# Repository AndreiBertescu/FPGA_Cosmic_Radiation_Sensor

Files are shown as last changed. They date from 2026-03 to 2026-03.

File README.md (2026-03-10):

# FPGA Cosmic Radiation Sensor (AICoRS)

This repository contains all materials related to the development of a cosmic radiation sensor board based on a Field-Programmable Gate Array (FPGA), as part of the project:

**"Artificial Intelligence-enabled Hardware Cosmic Radiation Sensor for Space Applications (AICoRS)"**  
PN-IV-P8-8.3-ROMD-2023-0068, in partnership between Transilvania University of Brașov and the Technical University of Moldova.

---

## Abstract

In the terrestrial space environment, radiation from Galactic Cosmic Rays (GCR), solar events, and trapped particles in the Earth's magnetosphere can interact with electronic circuits and cause **Single Event Effects (SEE)**, such as **Single Event Upsets (SEU)** and **Single Event Transients (SET)**. These effects pose significant challenges for high-performance and critical space systems, requiring dedicated detection methods and mitigation strategies.

This project presents the **design, implementation, and validation** of an FPGA-based cosmic radiation sensor board. The work includes:  

- FPGA device selection optimized for space applications  
- Hardware Description Language (HDL) development for SEU detection and communication  
- Printed Circuit Board (PCB) design for nanosatellite integration  
- Testing and validation of all components  
- Theoretical analysis of the space radiation environment and conversion of physical radiation parameters to memory bit change rates  

The developed sensor board has successfully passed validation and will be integrated with two other radiation detectors and a local On-Board Computer (OBC) as a Moldovan payload in the 3U **BIRDS-RPM** nanosatellite, scheduled for launch into **Low Earth Orbit (LEO)** via a resupply mission to the **International Space Station (ISS)** by **JAXA**.

---

## Repository Structure
FPGA_Cosmic_Radiation_Sensor<br>
├─ Arduino Test projects       --- Arduino experiments and test code <br>
├─ Kicad PCB projects          --- PCB designs for sensor board <br>
├─ Thesis latex project        --- Full thesis LaTeX source <br>
├─ Thesis latex template       --- Custom LaTeX template for IESC faculty <br>
├─ Verilog parts test projects --- Test benches and simulation projects for various subsystems <br>
├─ Verilog source code - V7.10 --- Full latest FPGA HDL source code for SEU detection <br>
├─ .gitignore                  --- Git ignore for Vivado, KiCdas, Latex and generated files <br>
├─ LICENSE                     --- CC BY-NC 4.0 license <br>
├─ LICENTA_Final.pdf           --- Final compiled thesis PDF <br>
├─ README.md                   --- This file <br>

---

## License

This work is licensed under a **[Creative Commons Attribution-NonCommercial 4.0 International License (CC BY-NC 4.0)](https://creativecommons.org/licenses/by-nc/4.0/)**.  

You are free to **share** and **adapt** the content for **non-commercial purposes**, with proper attribution to the author.

---

## Publications

The work conducted in this project has led to several scientific publications covering different stages, results, and aspects of the system development:

1. **Preliminary SEU Detection Algorithm**  
S. Popa, A. Kazak, A. Dinu et al., *“Architecture and Design Choices for an AI-enabled FPGA-based Cosmic Radiation Sensor,”* in 2024 International Symposium on Electronics and Telecommunications (ISETC), 2024, pp. 1–4.  
DOI: [10.1109/ISETC63109.2024.10797366](https://doi.org/10.1109/ISETC63109.2024.10797366)

2. **BIRDS Project Architecture & FPGA Sensor Comparison**  
N. Secrieru, V. Carbune, T. Zadorojneac et al., *“ARCHITECTURE OF THE SPACE RADIATION SENSOR SATELLITE MODULE BASED ON ARTIFICIAL INTELLIGENCE,”* JOURNAL OF ENGINEERING SCIENCE, vol. 31, nr. 4, pp. 73–83, Jan. 2025.  
DOI: [10.52326/jes.utm.2024.31(4).05](https://press.utm.md/index.php/jes/article/view/2024-31-4-05)

3. **FPGA-Based Radiation Sensor PCB Design**  
A. Bertescu and S. Popa, *“The Design and Implementation of an FPGA-Based Cosmic Radiation Sensor PCB,”* in 2025 18th International Conference on Engineering of Modern Electric Systems (EMES), 2025, pp. 1–4.  
DOI: [10.1109/EMES65692.2025.11045622](https://doi.org/10.1109/EMES65692.2025.11045622)

4. **Power and Cross-Section Optimization for FPGA Sensor**  
S. Popa, A. Bertescu, C. Furtună et al., *“Power and Cross-Section Optimization for an FPGA-Based Cosmic Radiation Sensor,”* in 2025 32nd IEEE International Conference on Electronics, Circuits and Systems (ICECS), 2025, pp. 1–4.

---

## Photos
### <br>Final AICoRS board
Photo no longer available

### <br>3D render of the AICoRS board
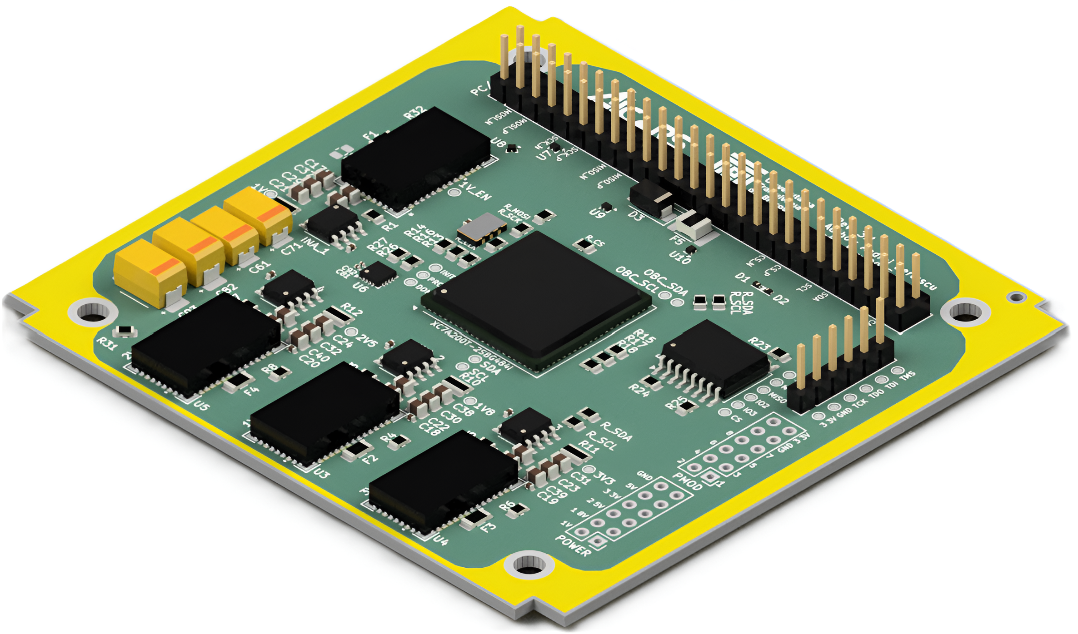
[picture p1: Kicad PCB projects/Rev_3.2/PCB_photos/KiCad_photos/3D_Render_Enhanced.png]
Photo no longer available


### <br>First version vs final version of the PCBs
Photo no longer available

### <br>BIRDS nanosatellite diagram 
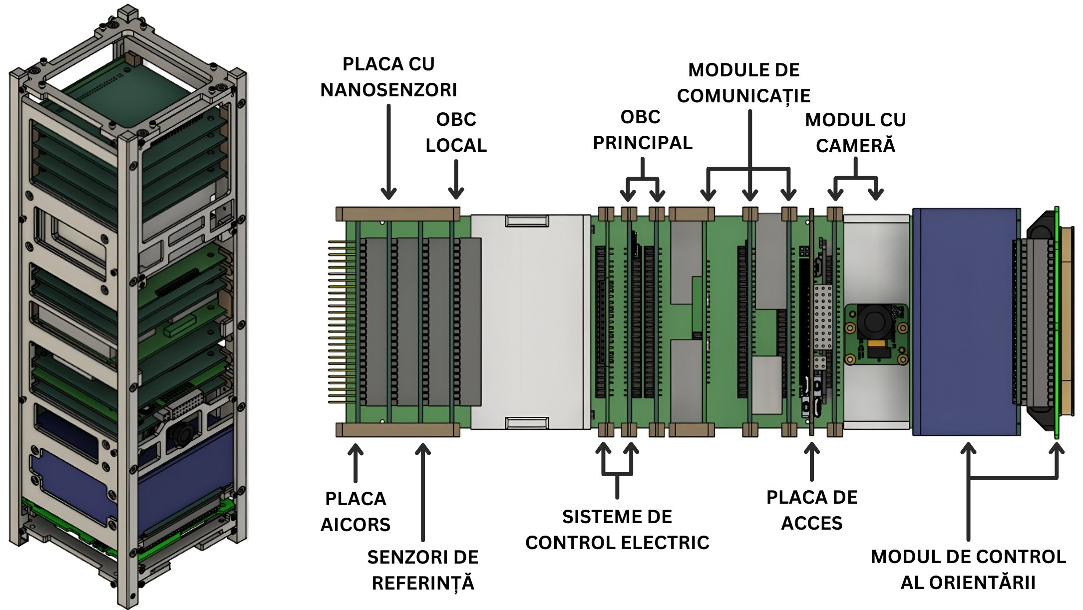
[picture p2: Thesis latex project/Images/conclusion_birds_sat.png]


### <br>Verilog program diagram
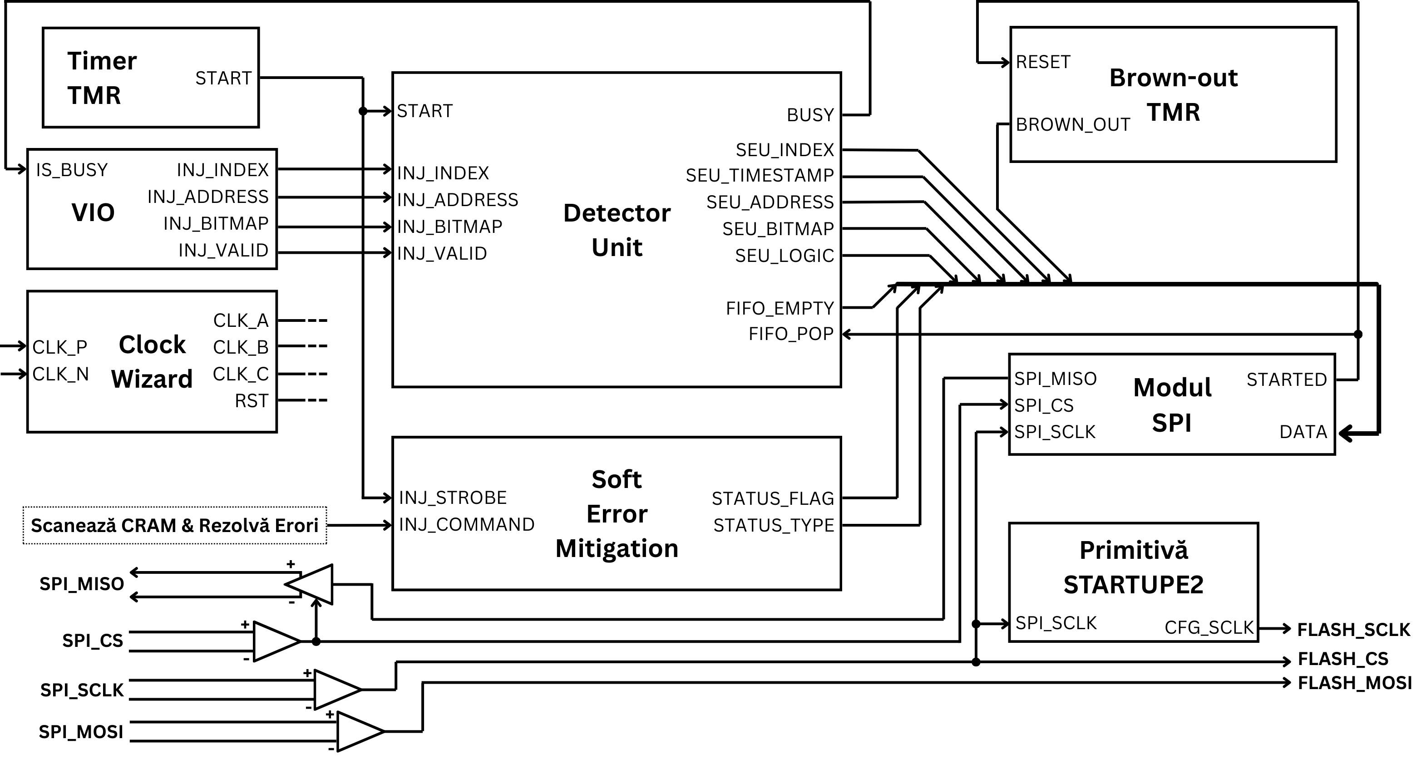
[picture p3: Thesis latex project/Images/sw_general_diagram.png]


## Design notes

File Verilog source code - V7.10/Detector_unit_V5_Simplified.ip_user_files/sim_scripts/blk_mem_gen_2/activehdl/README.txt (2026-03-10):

################################################################################
# Vivado (TM) v2024.1 (64-bit)
#
# README.txt: Please read the sections below to understand the steps required to
#             run the exported script and how to fetch design source file details
#             from the file_info.txt file.
#
# Generated by export_simulation on Mon Feb 03 11:43:21 +0200 2025
#
################################################################################

1. Steps to run the generated simulation script

From the shell prompt in the current directory, issue the following command:-

./blk_mem_gen_2.sh

This command will launch the 'compile', 'elaborate' and 'simulate' functions
implemented in the script file for the 3-step flow. These functions are called
from the main 'run' function in the script file.

The 'run' function first calls the 'check_args' function, the purpose of which
is to verify the generated script arguments and print error if incorrect switch
is specified. The 'run' function then calls the 'setup' function, the purpose of
which is to specify custom or initialization commands. The function also executes
following sub-functions:-
'reset_run' if -reset_run switch is specified.
'reset_log' if -reset_log switch is specified.

The purpose of 'reset_run' function' is to delete the simulator generated design
data from the previous run and the purpose of 'reset_log' function' is to delete
the simulator generated log files.

The 'run' function then calls the 'init_lib' function, the purpose of which is to
create design library mappings and directories. This function is called before the
'compile' step. By default, if '-step' switch is specified with the script then the
script will execute that specfic step, else it will execute all steps applicable
for the target simulator.

For more information on the script, please type './blk_mem_gen_2.sh -help'

2. Design source file information

export_simulation generates a 'file_info.txt' file that contains design file information
based on the compile order when export_simulation was executed from Vivado. The file
contains information about the file name, type, library it is compiled into, whether
it is part of the IP, associated library, file path information in a comma separated
format. This file can be parsed to extract the required information for generating a
custom script or can be read from verification test infra.

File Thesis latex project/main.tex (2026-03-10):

\documentclass[12pt,a4paper]{report}

% --------------------- PACKAGES ---------------------
\usepackage{fontspec}             % Custom font
\usepackage{pdfpages}             % Atach PDFs
\usepackage{graphicx}             % Images
\usepackage{amsmath,amssymb}      % Math
\usepackage{caption}              % Figure/table captions
\usepackage{booktabs}
\usepackage{colortbl}
\usepackage{subcaption}           % Subfigures
\usepackage{geometry}             % Margins
\usepackage{fancyhdr}             % Headers/footers
\usepackage{tocloft}              % ToC/List formatting
\usepackage[acronym,nonumberlist]{glossaries} % Acronyms
\usepackage[hidelinks]{hyperref}  % Hyperlinks
\usepackage{titlesec}             % Section title styling
\usepackage{listings}             % Source code
\usepackage{chngcntr}             % Counter tweaks
\usepackage{tabularx}             % Tables
\usepackage{tikz}                 % Graphs
\usepackage{pgfplots}             % Plots
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
  numberstyle=\scriptsize,
  breaklines=true,
  captionpos=b,
  frame=none,
  showstringspaces=false,
  xleftmargin=0.6cm,
}

% --------------------- ACRONYMS ---------------------
% ------- ADD ALL ACRONYMS HERE - REFERENCE THEM IN TEXT WITH \gls{name}
\newacronym{aicors}{AICoRS}{Artificial Intelligence-enabled Hardware Cosmic Radiation Sensor for Space Applications}
\newacronym{bga}{BGA}{Ball Grid Array}
\newacronym{bram}{BRAM}{Block Random-Access Memory}
\newacronym{can}{CAN}{Controller Area Network}
\newacronym{cmos}{CMOS}{Complementary Metal–Oxide–Semiconductor}
\newacronym{cram}{CRAM}{Configuration Random-Access Memory}
\newacronym{crc}{CRC}{Cyclic Redundancy Check}
\newacronym{cs}{CS}{Chip Select}
\newacronym{de}{DE}{Detector Element}
\newacronym{du}{DU}{Detector Unit}
\newacronym{ecc}{ECC}{Error Correction Code}
\newacronym{eeprom}{EEPROM}{Electrically Erasable Programmable Read-Only Memory}
\newacronym{enig}{ENIG}{Electroless Nickel Immersion Gold}
\newacronym{esa}{ESA}{Agenția Spațială Europeană}
\newacronym{ff}{FF}{Flip-Flop}
\newacronym{fifo}{FIFO}{First In, First Out}
\newacronym{fpga}{FPGA}{Field-Programmable Gate Array}
\newacronym{gcr}{GCR}{Galactic Cosmic Rays}
\newacronym{gpio}{GPIO}{General-Purpose Input/Output}
\newacronym{hdl}{HDL}{Hardware Description Language}
\newacronym{i2c}{I\textsuperscript{2}C}{Inter-Integrated Circuit}
\newacronym{ic}{IC}{Circuit Integrat}
\newacronym{io}{I/O}{Input/Output}
\newacronym{ip}{IP}{Intellectual Property}
\newacronym{iss}{ISS}{Stația spațială internațională}
\newacronym{jaxa}{JAXA}{Agenția Spațială Japoneză}
\newacronym{jtag}{JTAG}{Joint Test Action Group}
\newacronym{lansce}{LANSCE}{Los Alamos Neutron Science Center}
\newacronym{leo}{LEO}{Low Earth Orbit}
\newacronym{let}{LET}{Linear Energy Transfer}
\newacronym{lfsr}{LFSR}{Linear Feedback Shift Register}
\newacronym{lut}{LUT}{Look-Up Table}
\newacronym{lutram}{LUTRAM}{Look-Up Table Random Access Memory}
\newacronym{lvcmos33}{LVCMOS33}{Low-Voltage CMOS 3.3\,V}
\newacronym{lvds}{LVDS}{Low-Voltage Differential Signaling}
\newacronym{miso}{MISO}{Master In Slave Out}
\newacronym{mosfet}{MOSFET}{Metal-Oxide-Semiconductor Field-Effect Transistor}
\newacronym{mosi}{MOSI}{Master Out Slave In}
\newacronym{nasa}{NASA}{Administrația Națională pentru Aeronautică și Spațiu}
\newacronym{npth}{NPTH}{Non-Plated Through Hole}
\newacronym{obc}{OBC}{On-Board Computer}
\newacronym{pcb}{PCB}{Printed Circuit Board}
\newacronym{pmod}{Pmod}{Peripheral Module Interface}
\newacronym{pth}{PTH}{Plated Through Hole}
\newacronym{ram}{RAM}{Random-Access Memory}
\newacronym{rms}{RMS}{Root Mean Square}
\newacronym{sck}{SCK}{Serial Clock}
\newacronym{secded}{SECDED}{Single Error Correction, Double Error Detection}
\newacronym{see}{SEE}{Single Event Effect}
\newacronym{sel}{SEL}{Single Event Latch-up}
\newacronym{sem}{SEM}{Soft Error Mitigation}
\newacronym{set}{SET}{Single Event Transient}
\newacronym{seu}{SEU}{Single Event Upset}
\newacronym{smd}{SMD}{Surface-Mount Device}
\newacronym{spenvis}{SPENVIS}{Space Environment Information System}
\newacronym{spi}{SPI}{Serial Peripheral Interface}
\newacronym{sram}{SRAM}{Static Random-Access Memory}
\newacronym{tb}{TB}{Testbench}
\newacronym{tcl}{TCL}{Tool Command Language}
\newacronym{tht}{THT}{Through-Hole Technology}
\newacronym{tid}{TID}{Total Ionizing Dose}
\newacronym{tmr}{TMR}{Triple Modular Redundancy}
\newacronym{tvs}{TVS}{Transient Voltage Suppression}
\newacronym{uart}{UART}{Universal Asynchronous Receiver-Transmitter}
\newacronym{uram}{URAM}{Ultra Random-Access Memory}
\newacronym{usb}{USB}{Universal Serial Bus}
\newacronym{vio}{VIO}{Virtual Input/Output}
\newacronym{vlsi}{VLSI}{Very Large Scale Integration}

% --------------------- DOCUMENT ---------------------
% ------- UPDATE HERE WITH CORRESPONDING VALUES - NAME & TITLE
\newcommand{\studentname}{Bertescu Andrei}
\newcommand{\projecttitle}{Senzor inteligent de detecție a radiației cosmice, bazat pe FPGA, destinat nanosateliților}

\begin{document}

% ------- THIS DOCUMENT IS MADE SEPARATELY AND ADDED HERE
% ------- NO NEED TO MODIFY HERE
\includepdf[pages=-, pagecommand={\thispagestyle{plainfooter}}]
{Anexe/Prima pagina.pdf}

% ------- THE FOLLOWING PAGES ARE AUTOMATED - NO NEED TO MODIFY
\chapter*{Cuprins}
\vspace{-8em}
\tableofcontents
\newpage

\chapter*{Lista figurilor și tabelelor}
\addcontentsline{toc}{chapter}{Lista figurilor și tabelelor}

\section*{Figuri}
\vspace{-6em}
\listoffigures
\newpage

\section*{Tabele}
\vspace{-6em}
\listoftables
\newpage

\begingroup
\small
\setstretch{0.8}
\printglossary[type=acronym, style=list, nonumberlist, nogroupskip,title=Listă de acronime]
\endgroup
\addcontentsline{toc}{chapter}{Listă de acronime}
\newpage

% ------- THIS IS WHERE THE MAIN CONTENT GOES - EDIT HERE
\chapter{Introducere}
\section{Context și motivație}
Odată cu avansul tehnologic accelerat al umanității și evoluția domeniilor precum electronica, fizica și știința materialelor, aplicațiile aeronautice și spațiale capătă o importanță din ce în ce mai mare. Explorarea acestor medii extreme crește substanțial riscurile cauzate de radiația cosmică intensă prezentă în afara atmosferei. Din acest motiv, există un interes crescut în reducerea acestor pericole, prin studierea efectelor radiației ionizante, îmbunătățirea tehnologiilor de fabricare și protejare a componentelor, precum și detectarea și măsurarea nivelului de radiație. 

Tehnologiile actuale, însă, sunt adesea foarte specializate, folosesc materiale greu accesibile și sunt extrem de costisitoare. Lucrarea de față propune o alternativă mai accesibilă, bazată pe folosirea unui dispozitiv \gls{fpga} relativ ieftin, mai precis un Artix-7 de la Xilinx, pentru implementarea unui senzor inteligent de radiație cosmică. Dispozitivul \gls{fpga} va fi montat pe un \gls{pcb} proiectat să funcționeze la bordul unui nanosatelit de tip CubeSat.
% Acest senzor va integra un model de \gls{ai} pentru clasificarea și gruparea datelor colectate.

\section{Stadiul tehnologiei actuale}
\subsection{Senzori de radiație}
La momentul actual, există o multitudine de detectoare pentru radiație folosiți în acceleratoarele de particule, precum și în aplicații și experimente aerospațiale. Cele mai importante tipuri de senzori pentru detecția radiației cosmice sunt prezentate în~\cite{radiation_sensor_types}. În continuare, vor fi explicate modul de funcționare al fiecăruia și vor fi evidențiate avantajele și dezavantajele în contextul implementării pe un \gls{fpga}.
\begin{itemize}
    \item Detectorul cu ionizare în gaz: este alcătuit dintr-un tub metalic, umplut cu gaz, și un anod central, care măsoară impulsurile de curent cauzate de ionizarea gazului~\cite{gaseours_detectors}. Aceste tipuri de detectoare, precum tubul Geiger–Müller, camera de ionizare sau contorul proporțional, se află printre primele metode de a măsura nivelul de radiație și, deși sunt relativ simple și ușor de implementat în laborator, dimensiunile lor voluminoase le fac neadecvate pentru implementarea într-un nanosatelit.
    \item Detectoare cu scintilație: se folosesc de mai multe tipuri de materiale organice sau anorganice, care au proprietatea de a emite un puls de lumină când sunt traversate de particule ionizante. Lumina creată este amplificată de un tub fotomultiplicator și apoi măsurată. Aceste detectoare oferă un timp de răspuns foarte rapid și pot detecta o gamă largă de particule, însă tubul fotomultiplicator este voluminos, iar consumul de energie este ridicat (tensiuni de ordinul kilovolților pentru funcționare), ceea ce limitează utilizarea lor în aplicații compacte.
    \item Detectoare semiconductoare: funcționează pe baza proprietăților materialelor semiconductoare (siliciu sau germaniu) de a genera semnale electrice în urma ionizării de către o particulă suficient de energetică~\cite{silicon_detectors}. În comparație cu restul tipurilor de detectoare, aceștia par opțiunea ideală pentru aplicații compacte și foarte eficiente energetic. Energia necesară pentru a crea o pereche electron-gol este mult mai mică (3.6 eV) comparativ cu detectoarele pe bază de gaz sau scintilatoare (30 eV, respectiv 300 eV). Cu toate acestea, costurile ridicate de fabricație, necesitatea ecranării și a circuitelor de protecție împotriva zgomotului, precum și sensibilitatea la temperatură și la degradare în timp cauzată de radiație, pot reprezenta dezavantaje în contextul unor misiuni cu resurse limitate.
    \item Detectoare avansate sau dedicate, precum Radiation Assessment Detector (RAD) prezent pe \gls{iss} sau circuitele integrate Medipix~\cite{medipix} sau Radiation-sensing Field-Effect Transistor (RadFET)~\cite{radfet}, oferă performanțe excelente în detectarea radiației cosmice. Totuși, datorită complexității ridicate și costurilor mari, acestea sunt mai puțin potrivite pentru misiuni educaționale sau cu buget limitat.
\end{itemize}

\subsection{Tehnologii de protecție a cablajelor imprimate}
Cablajele imprimate destinate funcționării în mediul extrem al spațiului sunt nevoite să reziste vibrațiilor intense generate în timpul decolării, variațiilor termice extreme și radiației cosmice. Aceste \gls{pcb}-uri trebuie să adere standardelor stricte impuse de \gls{nasa} sau \gls{esa}~\cite{esa_pcb_standards} și trebuie să fie supuse unor teste extinse și costisitoare, fapt nepracticabil pentru proiecte relativ mici, provenite din mediile universitare sau de cercetare. Materialele utilizate în fabricarea \gls{pcb}-urilor aerospațiale sunt, de asemenea, costisitoare și greu accesibile, necesitând adesea colaborarea cu servicii de producție specializate. Se preferă materiale cu proprietăți termice superioare și performanță mai bună în vid, cum ar fi poliamidă sau variante modificate de FR-4. De multe ori, pentru protecția împotriva oxidării și pentru a întări rezistența structurală, marginile plăcii și zonele cu metal expus sunt acoperite cu un strat de tip \gls{enig}.

Componentele montate pe aceste \gls{pcb}-uri sunt la rândul lor selectate cu mare atenție, favorizându-se cele ce au mai fost utilizate în cadrul altor misiuni spațiale. Aceste componente trebuie să respecte toleranțe stricte și să reziste la temperaturi extreme, între -55 $^{\circ}$ C și +125 $^{\circ}$ C, depășind cerințele aplicațiilor comerciale. Totodată, toate elementele trebuie să fie întărite împotriva radiației (radiation hardened) sau să fie testate și recomandate de către agențiile spațiale~\cite{nasa_recomended_parts}. Se preferă pachetele ceramice sau metalice, în locul învelișurilor plastice. Pentru a îmbunătăți și mai mult rezistența la radiație și la zgomotul electromagnetic, componentele sensibile pot fi încapsulate într-o carcasă metalică, iar întregul \gls{pcb} poate fi acoperit cu un strat protector conform, care asigură protecție împotriva coroziunii, umidității și prafului.

\section{Obiective și constrângeri}
Pentru ca această placă să funcționeze fiabil în mediul spațial și să poată fi integrată într-un nanosatelit, trebuie să depășească mai multe provocări generate de condițiile extreme și spațiul redus. În primul rând, \gls{pcb}-ul trebuie să fie compact, având dimensiunile fixe de 86 $\times$ 90 $\times$ 11 mm, cu un spațiu și mai mic pentru plasarea componentelor. Consumul de energie nu trebuie să depășească 2 W, iar sistemul trebuie să reziste la pierderi bruște de alimentare și la vârfuri de tensiune. Toată placa interfațează cu restul satelitului printr-un singur conector cu 52 de pini, ceea ce înseamnă că toate interfețele de comunicare și liniile de alimentare pornesc din aceeași zonă a plăcii. Pentru alimentarea \gls{fpga}-ului sunt necesare patru tensiuni diferite: 3.3 V, 2.5 V, 1.8 V și 1 V, tensiuni care trebuie generate local, satelitul furnizând doar 5 V. Comunicarea \gls{fpga}-ului cu \gls{obc}-ul satelitului se realizează printr-o singură interfață \gls{lvds} \gls{spi}, alte interfețe fiind disponibile, dar considerate neprioritare. În plus, dispozitivul trebuie să fie autonom față de restul satelitului și să nu necesite configurare externă \gls{pcb}-ului. Din acest motiv, fișierele de configurare sunt stocate pe un cip de memorie non-volatilă amplasat lângă \gls{fpga}.

În calitate de componentă activă a plăcii, \gls{fpga}-ul trebuie să detecteze radiația cosmică (în special \gls{seu}, detaliați în Capitolul~\ref{cosmic_radiation_theory}), să înregistreze aceste evenimente și, la un interval precizat, să le transmită \gls{obc}-ului prin interfața \gls{lvds} \gls{spi}. Totodată, \gls{fpga}-ul monitorizează consumul de curent și nivelele de tensiune atât ale cipului, cât și ale celor patru șine de alimentare, comunicând prin interfața \gls{i2c} cu patru senzori de curent integrați pe \gls{pcb}. Fiind susceptibil radiației cosmice, acesta trebuie să utilizeze metode de protecție, precum \gls{tmr}, pentru prevenirea erorilor, să monitorizeze integritatea memoriei sale de configurare, iar în cazul apariției unor erori, să repare partea afectată sau să se reprogrameze folosind configurări stocate pe cipul de memorie non-volatilă.

Obiectivul principal al acestei lucrări este documentarea procesului de proiectare, implementare și testare a unui senzor de radiație cosmică bazat pe un \gls{fpga}, precum și a unui \gls{pcb} capabil să susțină funcționarea acestui detector. Dispozitivul realizat trebuie să depășească provocările tehnice menționate, atât la nivel software, cât și hardware, și să fie pregătit pentru integrare într-un nanosatelit. Pe partea software, va fi detaliat procesul de proiectare, simulare și testare a programului Verilog menit să detecteze radiația cosmică, să comunice cu \gls{obc}-ul și cu alte dispozitive de pe \gls{pcb}, și să mențină integritatea acestuia. Partea hardware va documenta alegerea \gls{fpga}-ului ideal, proiectarea \gls{pcb}-ului suport, testarea ansamblului și rezolvarea problemelor găsite. De asemenea, lucrarea va include o analiză a costurilor și a consumului de energie, precum și o evaluare a fezabilității implementării în mediul spațial real. În final, lucrarea urmărește să demonstreze că soluțiile propuse pot prezenta o alternativă fiabilă și eficientă la sistemele tradiționale de detecție a radiației, în special pentru misiuni științifice cu buget redus sau proiecte academice dedicate explorării spațiului.

\section{Structura lucrării}
Lucrarea este structurată în trei părți principale, organizate cronologic în funcție de desfășurarea proiectului. În completarea acestor capitole principale, lucrarea va conține și o parte teoretică introductivă, menită să ofere cititorului un context adecvat, precum și o secțiune finală de concluzii și sugestii pentru îmbunătățiri viitoare, în care sunt prezentate rezultatele obținute, direcții de dezvoltare și pașii următori. 

Prima parte va detalia toate aspectele legate de \gls{fpga}: de la alegerea dispozitivului potrivit,  până la proiectarea structurii de detecție a radiației, dezvoltarea modulelor de comunicație, precum și testarea și simularea acestora. A doua parte documentează procesul de proiectare a \gls{pcb}-ului și procesul de rezolvare a constrângerilor impuse de montarea într-un satelit. Este descrisă proiectarea primei versiuni a plăcii prototip, identificarea erorilor și îmbunătățirea acesteia, finalizată prin realizarea unei a doua versiuni, care are rolul de variantă finală, pregătită pentru lansare. Ultima parte tratează metodologia de testare a întregului ansamblu, precum și a componentelor individuale, din punct de vedere electric și funcțional. Sunt incluse teste termale, măsurători de consum și de integritate a semnalului, dar și verificări ale funcționării corecte a \gls{fpga}-ului și ale comunicației acestuia cu \gls{obc}-ul și alți senzori conectați.

\section{Mențiuni și contextul proiectului AICoRS}
Această lucrare se bazează pe activitatea desfășurată în cadrul proiectului PN-IV-P8-8.3-ROMD-2023-0068 intitulat \enquote{\gls{aicors}}, contract nr. 2ROMD/01.06.2024, desfășurat în parteneriat între Universitatea Transilvania din Brașov și Universitatea Tehnică a Moldovei (UTM). În cadrul acestui proiect au fost dezvoltate două variante de plăci electronice, realizate de fiecare dintre cele două instituții, având la bază același cod \gls{fpga} destinat detecției radiației cosmice. Una dintre aceste plăci urmează să fie integrată ca parte a payload-ului dezvoltat de UTM, care conține trei tipuri de detectoare cosmice experimentale și un \gls{obc} local, din cadrul nanosatelitului BIRDS-RPM, lansat de către \gls{jaxa}.

% ---------------------------------------------------------------

\chapter{Fundamente teoretice}
\section{Radiația cosmică}%
\label{cosmic_radiation_theory}
În afara atmosferei terestre, nivelul de radiație ionizantă este foarte ridicat, din cauza lipsei scuturilor naturale care protejează suprafața pământului, precum stratul de ozon și câmpul magnetic terestru. În acest loc lipsit de oxigen circulă o multitudine de particule provenite de la soare, din exteriorul sistemului nostru solar și chiar din alte galaxii. Aceste particule încărcate electric, ce traversează spațiul aproape cu viteza luminii, sunt de fapt electroni, protoni și, în mică măsură, nuclee de dimensiuni mai mari (numite particule alfa), care provin din cele mai energetice evenimente ale universului nostru: supernove, quasari, centre galactice și explozii de raze gamma~\cite{nasa_blog_radiation}.
Când aceste particule, care pot avea energii între \(10^6\) și \(10^{21}\) eV~\cite{cosmic_rays_energy}, trec printr-un semiconductor, își depun energia și creează o zonă activă în material, unde se formează perechi electron-gol care modifică comportamentul electric local. Dacă suficiente particule lovesc zone mai sensibile dintr-un dispozitiv, precum drena unui tranzistor, o celulă \gls{sram} sau intrarea unui \gls{ff}, pot schimba caracteristicile electrice ale acestor dispozitive și pot crea erori software sau defecțiuni electrice permanente~\cite{fpga_radiation_effects}. 

\begin{figure}[h!]
    \centering
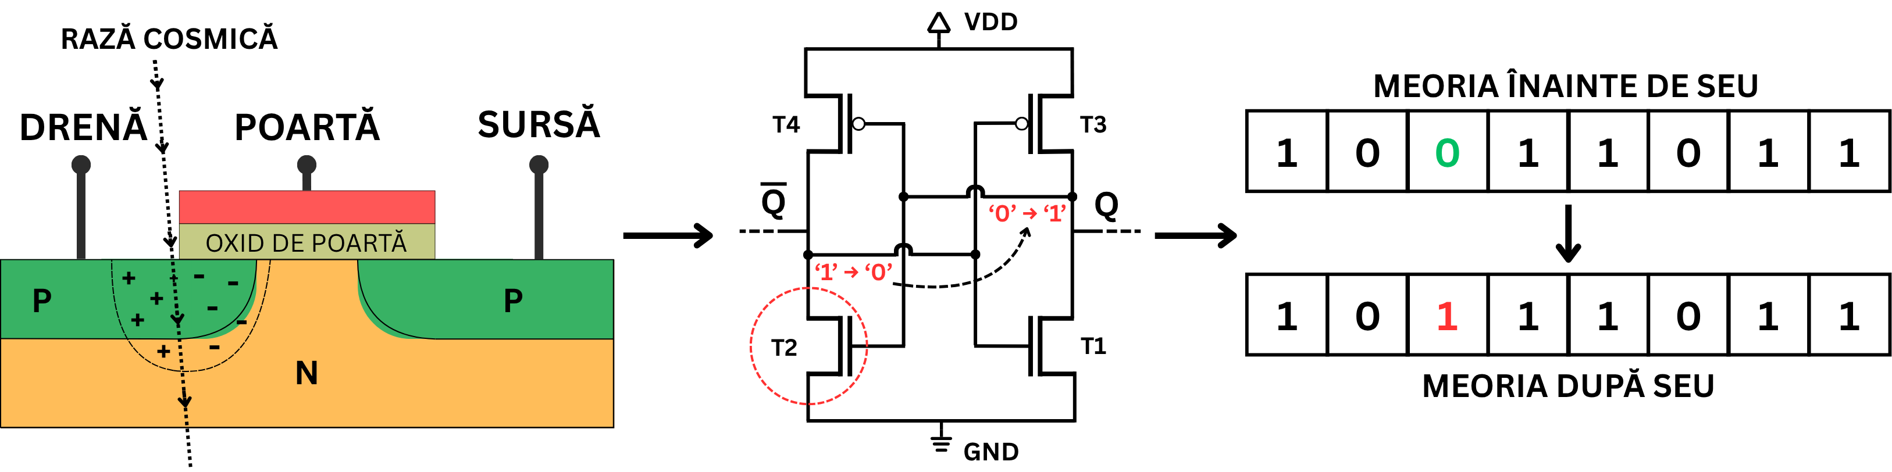
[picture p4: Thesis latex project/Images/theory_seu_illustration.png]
    
    \caption{Exemplificarea unui SEU care cauzează un bit-flip într-o celulă SRAM 6T.}%
\label{fig:theory_seu_illustration}
\end{figure}

Consecințele negative apărute din cauza radiației cosmice pot fi clasificate în efecte imediate și efecte de lungă durată. Cu cât un tranzistor de tip Metal–Oxide–Semiconductor (MOS) este expus mai mult timp la o sursă de radiație ionizantă, cu atât acumularea de sarcină parazită crește, schimbându-i caracteristici esențiale precum tensiunea de prag, curentul de scurgere și aspecte privind sincronizarea acestuia.\@ \gls{tid} reprezintă cantitatea de radiație la care poate rezista dispozitivul, până când acesta nu își mai îndeplinește parametrii specificați.\@ \gls{tid} se măsoară în gray (Gy) (unitate care exprimă cantitatea de energie absorbită de un material) și reprezintă o schimbare permanentă și nealterabilă a caracteristicilor electrice ale dispozitivului.

Pe lângă efectele permanente cauzate de radiația cosmică, mai există și perturbări imediate, generate de particule cu energie foarte mare, care pot afecta instantaneu logica internă a unui circuit integrat. Cele mai importante astfel de fenomene sunt descrise în continuare:
\begin{itemize}
    \item \textbf{\gls{seu}}: este un eveniment ce apare când o particulă lovește intrarea unui \gls{ff} sau un tranzistor dintr-o celulă \gls{sram}. Acest eveniment este ilustrat în Figura~\ref{fig:theory_seu_illustration} și funcționează astfel: dacă energia depusă de o particulă individuală este suficientă, se poate crea o schimbare în starea celulei \gls{sram} sau se poate capta o valoare eronată de către \gls{ff}. Un \gls{seu} se propagă ca o greșeală în datele stocate, greșeală care poate duce la erori software. Acesta nu introduce efecte sau modificări permanente la nivelul fizic al componentelor electrice.
    \item \textbf{\gls{sel}}: la dispozitivele construite dintr-un material semiconductor pot apărea anumite structuri care, dacă sunt activate, pot avea efecte neprevăzute și catastrofale. Spre exemplu, în fabricarea circuitelor integrate în tehnologia \gls{cmos} apar și perechi de tranzistori bipolari PNP și NPN care pot forma un tiristor~\cite{parasitic_transistors}. O particulă suficient de energetică poate activa această structură, astfel creându-se o cale de impedanță scăzută între Vdd și Gnd. Dacă alimentarea dispozitivului nu este îndepărtată în scurt timp, acest scurt circuit va distruge circuitul integrat.
    \item \textbf{\gls{set}}: când particula energetică lovește un circuit logic, apare un vârf de tensiune tranzitoriu care se poate propaga prin elementele combinaționale ale circuitului și poate fi captat de un element secvențial, astfel transformându-se într-un \gls{seu}. Dacă acest tranzitoriu nu are suficientă energie pentru a traversa toată logica și pentru a ajunge la un \gls{ff}, evenimentul nu va avea nici-un efect asupra funcționării dispozitivului. Un \gls{set} nu produce efecte fizice permanente, ci poate produce doar erori software.
\end{itemize}

\section{Field-Programmable Gate Array}
La începuturile erei tehnologice, majoritatea circuitelor electronice erau alcătuite din cipuri discrete, fiecare având o funcționalitate simplă și un rol propriu: cipuri pentru operații aritmetice și logice, cipuri de memorie, numărătoare, multiplexoare și decodoare~\cite{74series}. La sfârșitul anilor 1970 însă, procesul \gls{vlsi} și tehnologia \gls{cmos} au permis crearea unor circuite integrate complexe, care îndeplinesc funcții mult mai avansate decât predecesorii lor. Un astfel de Application-Specific Integrated Circuit (ASIC) poate îndeplini toate funcțiile care cu un deceniu în urmă erau îndeplinite de multiple cipuri independente~\cite{intel_4004}\cite{zilog_z80}. În același timp s-au introdus și dispozitive de tip \gls{fpga} ca un răspuns la obstacolele dezvoltării unui ASIC.\@ În principal, \gls{fpga}-urile rezolvă problema costului ridicat al unui circuit integrat și reduc riscul proiectării acestuia prin introducerea capacității de reconfigurare și reprogramare. ASIC-urile moderne au un cost de dezvoltare și fabricație cuprins între 150.000 USD, până la zeci de milioane de USD~\cite{asic_costs_1}\cite{asic_costs_2}. Această sumă se desparte în două categorii diferite: costuri de proiectare și costul per unitate al cipului de siliciu. Procesul de proiectare, sau Non-Recurring Engineering (NRE), este de departe cel mai costisitor aspect al unui ASIC, datorită necesității de a testa și a simula circuitul logic și datorită licențelor și pachetelor de \gls{ip} necesare proiectării acestuia.

\gls{fpga}-urile sunt folosite răspândit pentru prototipare și cercetare, pentru aplicații ce nu necesită un număr suficient de mare de bucăți ca să justifice producerea unui ASIC și pentru controlul proceselor industriale~\cite{basic_fpga}. Cei mai mari producători de dispozitive \gls{fpga} sunt Xilinx și Altera, recent achiziționate de AMD, respectiv Intel. Spre deosebire de ASIC-uri, care odată ce sunt proiectate nu pot fi modificate, un \gls{fpga} este alcătuit din mai multe tipuri de componente reconfigurabile: Configurable Logic Block (CLB)-uri, memorii, blocuri de \gls{io} și trasee de interconectare. CLB-urile sunt componentele de bază ale \gls{fpga}-ului și se găsesc în număr cel mai mare. Ele sunt alcătuite dintr-un \gls{lut} și un adunător, conectate la un \gls{ff}, astfel creându-se o mașină de stări finite în miniatură. Pe lângă CLB-uri, mai pot exista și blocuri Digital
Signal Processing (DSP), care sunt optimizate pentru operații aritmetice dificil de implementat din alte componente logice (multiplicare, divizie, acumulare și combinații ale acestora). La marginea cipului se găsesc blocurile \gls{io}, care conțin diferite tipuri de buffere (unidirecționale și bidirecționale) pentru adaptarea semnalelor la diferitele standarde logice și niveluri de tensiune. Cel mai limitator aspect al unui dispozitiv \gls{fpga} însă, este logica de interconectare. Limitările rețelei de interconectare dintr-un \gls{fpga} reduc drastic frecvența maximă de operare și cresc cantitatea de energie consumată, în comparație cu un ASIC echivalent~\cite{fpga_book}.

Aceste elemente sunt programate prin intermediul unei memorii interne speciale, numită memorie de configurare. Poate fi de mai multe tipuri, precum memorie flash, \gls{eeprom} sau antifuse. În schimb, cea mai des întâlnită este memoria \gls{sram}. Deși este volatilă și nu își menține datele cât timp nu este alimentată, este cel mai folosit tip de memorie datorită vitezei și densității acesteia. Pentru a programa \gls{fpga}-ul este necesară generarea unui fișier bitstream. Crearea acestuia reprezintă un proces îndelungat care este parcurs în mai multe etape:
\begin{itemize}
\item Un inginer hardware scrie o configurare într-un \gls{hdl} precum Verilog, SystemVerilog sau VHSIC Hardware Description Language (VHDL). Aceste limbaje nu sunt ca limbajele de programare software. Ele sunt folosite pentru a descrie comportamentul circuitului integrat la nivel de elemente logice ale unui circuit, precum \gls{ff}-uri, multiplexoare sau porți logice.
\item Într-un fișier \gls{hdl} se definește un modul, având intrări și ieșiri, care îndeplinește un scop precizat. În modul se găsesc fire (wire), prin care se definește logică combinațională, și regiștri (reg), definiți în blocuri always, care stochează valori. 
\item După scriere, fișierul \gls{hdl} este simulat într-un program Electronic Design Automation (EDA) precum Vivado, Quartus sau ModelSim. Se testează funcționalitatea corectă a modulului prin intermediul unui fișier test-bench, sau se generează și se verifică forme de undă pentru semnalele de interes.
\item Dacă modulul hardware a trecut faza de testare, este trecut prin procesele de lintare, sintetizare și implementare. Aceste etape transformă modulul hardware inteligibil uman într-un fișier netlist, care descrie configurarea \gls{fpga}-ului la nivel de porți logice. Nu necesită intervenția utilizatorului și sunt complet automatizate de către programele EDA și Computer-Aided Design (CAD).
\item Fișierul netlist rezultat este apoi transformat într-un fișier cu format binar, numit bitstream, care poate fi încărcat în memoria de configurare a \gls{fpga}-ului prin interfața \gls{jtag}.
\end{itemize}

\section{Printed Circuit Board}
Un \gls{pcb}, sau cablaj imprimat, este o structură alcătuită din două sau mai multe straturi de material izolator și de material conductiv care au rolul de a conecta un ansamblu de componente electronice între ele. Acestea și-au făcut apariția la începutul anilor 1950 și au înlocuit cablajele realizate direct, prin legarea unor fire individuale între bornele componentelor montate pe un șasiu.\@ \gls{pcb}-urile sunt folosite la aproape toate dispozitivele electronice din ziua de azi, iar industria de fabricare a acestora depășește 71 de miliarde USD~\cite{pcb_market_cap}.

Un \gls{pcb} modern poate avea între 2 și 8 straturi pentru aplicațiile comerciale și între 8 și 32 de straturi pentru aplicațiile militare și telecomunicații. Sunt alcătuite din fire metalice aplatizate (numite trace-uri), care fac conexiunea electrică între componente. Cel mai des folosit material este cuprul, ales datorită conductivității sale electrice foarte bune, abilității excelente de a disipa căldura, proprietăților mecanice, dar și datorită prețului acestuia, în comparație cu alte materiale bune conductoare, precum argintul sau aurul. Pentru a conecta două sau mai multe straturi metalice între ele, se folosesc vias-uri. Un via este o gaură făcută în placă, care este ulterior acoperită prin depunere galvanică de cupru~\cite{vias_explination}. Vias-urile pot fi de trei tipuri: through-hole, blind și buried. Vias-urile through-hole trec dintr-un capăt al plăcii până în celălalt, chiar dacă se vrea conectarea a doar două straturi. Blind vias-urile nu trec prin toată placa, ci sunt vizibile doar pe o parte a \gls{pcb}-ului, iar buried vias-urile se află complet în interiorul plăcii și, în consecință, conectează doar straturi interne. 

Pentru a izola electric straturile metalice și pentru a oferi o structură rigidă \gls{pcb}-ului, se introduc straturi făcute dintr-un material dielectric, confecționate din hârtie sau țesătură, impregnate cu diferite tipuri de rășină. Aceste materiale sunt alese și combinate pentru a îmbunătăți proprietățile electrice și mecanice adaptate aplicației. Cel mai întâlnit tip de dielectric este FR-4 (țesătură din fibră de sticlă impregnată cu o rășină epoxidică ignifugă), ales pentru costul redus, proprietăți electrice excelente (rezistență dielectrică ridicată și pierderi dielectrice reduse) și rezistență structurală și la foc. FR-4 este suficient în majoritatea situațiilor comerciale și industriale, însă pentru anumite aplicații ce necesită lucrul cu frecvențe foarte mari sau lucrul în spațiu, se folosesc materiale mai scumpe și mai performante precum CEM-1, CEM-3, PTFE sau materiale flexibile precum poliamidă~\cite{pcb_materials}. La finalul procesului de fabricare al unui \gls{pcb} se acoperă suprafața acestuia cu un strat de epoxy fotosensibil izolator numit solder mask. Acesta protejează straturile externe de cupru de mediul înconjurător și de evenimente accidentale de scurt-circuit și oferă culoarea caracteristică unui \gls{pcb} (verde, roșu, albastru sau alte culori).

\begin{figure}[h!]
    \centering
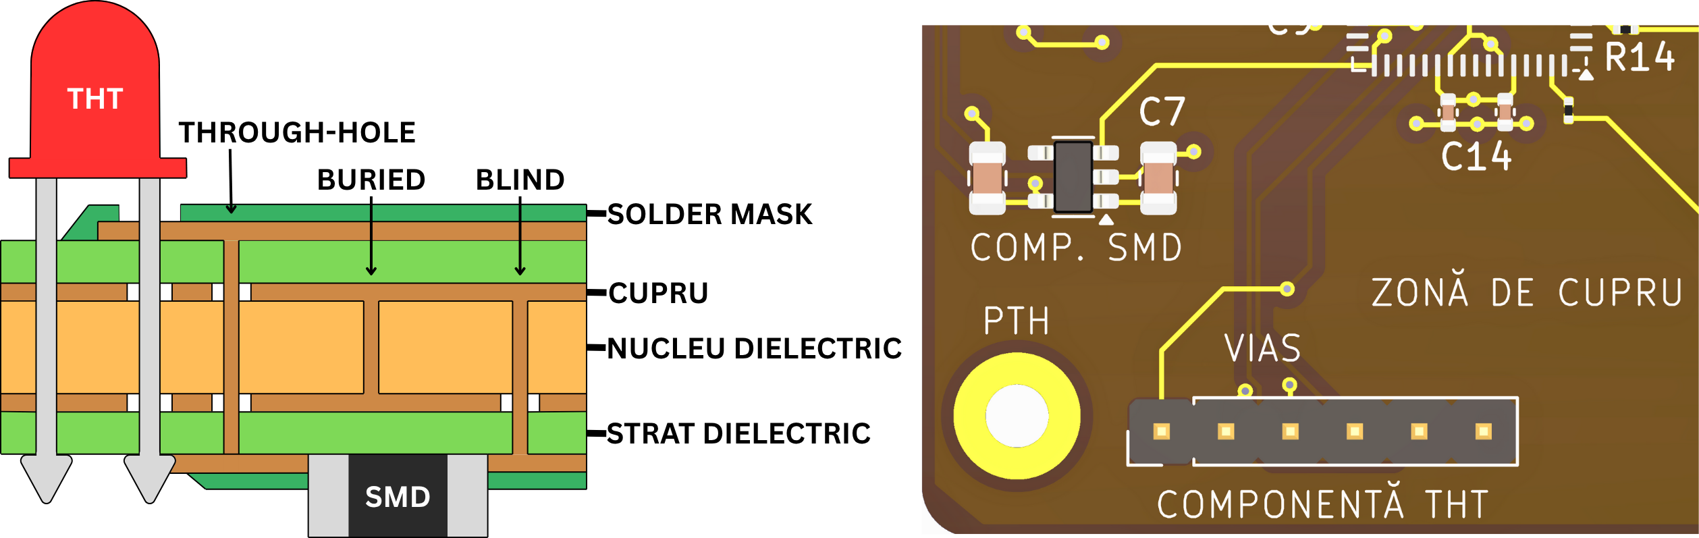
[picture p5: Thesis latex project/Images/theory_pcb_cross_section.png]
    
    \caption{Structura unui PCB cu patru straturi, cu componente THT și SMD.}%
\label{fig:theory_pcb_cross_section}
\end{figure}

Structura transversală și cea longitudinală a unui \gls{pcb} sunt ilustrate în Figura~\ref{fig:theory_pcb_cross_section}. Sunt exemplificate tipurile de vias-uri și de componente, precum și structura internă a unui cablaj imprimat. Mai departe vor fi definiți și explicați diverși termeni de interes pentru proiectarea și fabricarea unui \gls{pcb}, cum ar fi tipurile de găuri metalizate și nemetalizate, scrierea de text, ilustrații, trasee și componente:
\begin{itemize}
\item Firele aplatizate ce aparțin straturilor metalice se numesc \textit{trasee} (traces) și, la rândul lor, pot fi de mai multe tipuri. Toate traseele de pe straturile exterioare se numesc microstrip și sunt folosite pentru a reduce costul de fabricație și pentru a ușura accesul și procesul de depanare. Traseele de pe straturile interioare se numesc stripline. Acestea sunt folosite pentru a avea un control mult mai mare asupra impedanței și integrității semnalului. În funcție de tipul de semnal transmis printr trasee, acestea pot fi single-ended sau diferențiale. În cazul perechilor diferențiale, trebuie să se acorde o atenție deosebită dimensiunilor fiecărui traseu și distanței între ele, pentru a menține impedanța caracteristică interfeței de comunicație.
\item Exista două tipuri de găuri mecanice prezente pe un \gls{pcb}. Toate găurile care au un strat de metalizare pe lungimea acestora (ca și în cazul vias-urilor) se numesc \textit{\gls{pth}}, pe când toate cele ce nu sunt metalizate se numesc \textit{\gls{npth}}. Găurile \gls{pth} sunt folosite atunci când se dorește conectarea a mai multor straturi metalice între ele sau la lipirea pinilor componentelor electrice. Cele \gls{npth} sunt pur mecanice și se folosesc de obicei pentru montare.
\item Un \gls{pcb} poate fi proiectat pentru a conecta două tipuri diferite de componente, caracterizate de modalitatea de atașare a acestora. Componentele \textit{\gls{tht}} se folosesc de fire conectoare, care sunt inserate prin placă și lipite pe partea opusă. Componentele de tip \textit{\gls{smd}} se debarasează de aceste fire și sunt lipite direct pe partea plăcii la care sunt atașate.
\item Când o componentă este plasată pe placă, ea este reprezentată grafic de un \textit{footprint}. Majoritatea componentelor electrice au o forma și un pachet standardizat, cele mai des întâlnite tipuri fiind: i) pini de o parte și de alta a componentei dreptunghiulare (Small Outline Integrated Circuit, SOIC), ii) pini pe toate cele patru laturi unei componente pătrate (Quad Flat Package, QFP), iii) pini integrați direct în carcasa circuitului integrat (Quad Flat No-lead, QFN) și iv) mici bile de metal dispuse într-o matrice pe partea inferioară a capsulei (Ball Grid Array, BGA). Ultimul tip enumerat este folosit cel mai des pentru procesoare, \gls{fpga}-uri și circuite integrate complexe, ce necesită un număr de pini foarte mare. Cu cât crește nivelul de integrare a capsulei, cu atât crește și complexitatea procesului de lipire a componentei pe \gls{pcb}, precum și dificultatea de rutării traseelor către pini.
\item Ordinea de aranjare a straturilor metalice și dielectrice, împreună cu definirea dimensiunii acestora, tipului de material și constantele dielectrice, sunt organizate într-un tabel numit \textit{stackup}.
\item Orice text, grafică sau linii explicative care sunt imprimate pe \gls{pcb} în culoarea alb (cea mai des utilizată, datorită contrastului oferit fată de culoarea solder mask-ului. Pentru solder mask de culoarea albă, se folosește text negru)  sunt definite în stadiul de proiectare pe un strat special numit \textit{silkscreen}.
\end{itemize}

% ---------------------------------------------------------------

\chapter{Proiectarea și implementarea sistemelor pe FPGA}
\section{Alegerea FPGA-ului ideal}
Fiind componenta centrală a sistemului, alegerea dispozitivului \gls{fpga} ideal a fost realizată cu deosebită atenție, cu obiectivele de a minimiza consumul de energie electrică și de a oferi o eficacitate cât mai mare senzorului, fie prin dimensiunea elementului detector, fie prin creșterea secțiunii transversale. Rezultatele preliminare ale acestui proces de selecție sunt prezentate în~\cite{jes} și vor fi detaliate în secțiunile următoare. Au fost testate și comparate cele mai performante două dispozitive din fiecare dintre familiile Artix-7 și Artix UltraScale+, precum și cele mai puțin performante două dispozitive din seria Kintex UltraScale+ (US+)~\cite{7series_product_selection, ultrascale_product_selection}. Sunt prezente doar \gls{fpga}-uri produse de Xilinx, și nu Intel (fost Altera), deoarece experiența anterioară a echipei s-a concentrat exclusiv pe această platformă. De asemenea, laboratorul în care s-a desfășurat proiectul dispunea deja de două plăci de dezvoltare cu \gls{fpga}-uri Xilinx, ceea ce a favorizat utilizarea acestui ecosistem și a redus necesitatea de achiziții suplimentare și de formare pe alte arhitecturi. Alți producători mai mici, precum Lattice sau Microchip nu au fost luați în considerare din cauza suportului software limitat și pentru că majoritatea produselor acestora sunt orientate fie aplicațiilor comerciale simple, fie unora mult prea specializate.

\subsection{Analiză a produselor disponibile}
Paralela între \gls{fpga}-urile analizate este prezentată în Tabelul~\ref{tab:sw_fpga_comparison}. Sunt incluse informații privind denumirea și familia fiecărui dispozitiv, numărul de resurse logice disponibile, capacitatea memoriei de tip \gls{bram}, precum și cel mai mic preț găsit pentru o singură unitate. Dintre toți parametrii considerați, cei mai importanți au fost numărul de memorii \gls{bram}, fiind esențiale pentru implementarea detectorului de radiație, precum și prețul unității. Un număr mai mare de \gls{bram}-uri permite o implementare mai eficientă a senzorului, în timp ce un preț redus ajută la fabricarea și popularea unui număr mai mare de plăci, facilitând testarea extinsă și experimentarea în diverse scenarii. Deși dispozitivele din familia Kintex US+ au cele mai multe resurse logice și includ,  pe lângă memoria \gls{bram}, un tip adițional numit \gls{uram}~\cite{fpga_memory_types}, cu dimensiunea fiecărui bloc de 288 Kb, acestea sunt prea costisitoare pentru aplicația vizată. În plus, au un număr de \gls{bram}-uri similar cu celelalte opțiuni mult mai accesibile. De exemplu, modelul KU5P este de 8.3 ori mai scump decât XC7A200T, oferind doar cu 24\% mai multe memorii \gls{bram}. Din aceleași motive, au fost excluse și dispozitivele din familia Artix US+, acestea având mai puține memorii decât predecesorii lor din seria Artix-7, fără a aduce avantaje semnificative care să justifice creșterea prețului. În plus, capsulele dispozitivelor US+ sunt mai mari (23 mm sau 27 mm) decât Artix-7 (19 mm), ceea ce îngreunează integrarea acestuia într-un \gls{pcb} compact impus de aplicația spațială.

\begin{table}[ht!]
  \centering
  \renewcommand{\arraystretch}{1.6}
  \caption{Analiză comparativă a unor FPGA-uri similare.}%
  \label{tab:sw_fpga_comparison}
  \begin{tabular}{l c c c c c c c r}
    \toprule
    \textbf{Familie} & \textbf{Nume} & \textbf{FF} & \textbf{LUT} & \textbf{DSP} & \textbf{URAM} & \textbf{BRAM} & \textbf{BRAM [Kb]} & \textbf{Preț} \\
    \midrule
    Artix-7 & XC7A100T & 126.800 & 63.400 & 240 & --- & 135 & 4.860 & \$258 \\
    Artix-7 & XC7A200T & 269.200 & 134.600 & 740 & --- & 365 & 13.140 & \$370 \\
    \midrule
    Artix US+ & AU20P & 218.000 & 109.000 & 900 & --- & 200 & 7.200 & \$587 \\
    Artix US+ & AU25P & 282.000 & 141.000 & 1200 & --- & 300 & 10.800 & \$700 \\
    \midrule
    Kintex US+ & KU3P & 325.440 & 162.720 & 1368 & 48 & 360 & 12.960 & \$2252 \\
    Kintex US+ & KU5P & 433.920 & 216.960 & 1824 & 64 & 480 & 17.280 & \$3056 \\
    \bottomrule
  \end{tabular}
\end{table}

\subsection{Sensibilitatea la radiație}
În final a fost ales dispozitivul XC7A200T din familia Artix-7, datorită raportului \gls{bram}-preț cel mai bun, dar și pentru numărul de resurse logice adecvate cerințelor aplicației. Deși familia Artix-7 este considerată relativ învechită (primele produse fiind lansate din 2012) și este realizată printr-un proces de fabricație pe 28 nm, trebuie avută în vedere și sensibilitatea acestora la radiația cosmică. Valorile prezentate în Tabelul~\ref{tab:sw_fpga_cross_section} sunt preluate din~\cite{amd_reliability_report}, unde este documentată fiabilitatea dispozitivelor de la Xilinx, în special sensibilitatea și secțiunea transversală a memoriilor \gls{bram} și \gls{cram} pentru diferite familii de \gls{fpga}-uri, în urma testelor realizate la \gls{lansce}. În cadrul experimentelor a fost inclusă și memoria \gls{cram} pentru că este, la rândul său, sensibilă la radiația cosmică. Mai mult, aceasta joacă un rol esențial în buna funcționare a dispozitivului, fiind responsabilă pentru stocarea configurației interne a \gls{fpga}-ului. Comparativ cu memoria \gls{bram}, \gls{cram}-ul este mult mai extins, ajungând la o capacitate de 74 Mb în cazul dispozitivului XC7A200T, față de doar 13 Mb de memorie \gls{bram}.

\begin{table}[h!]
  \centering
  \renewcommand{\arraystretch}{1.6}
  \caption{Secțiunea transversală și rata de erori pentru diverse familii de FPGA-uri.}%
  \label{tab:sw_fpga_cross_section}
  \begin{tabular}{c c C{3.6cm} C{3.6cm} C{1.6cm} C{1.6cm}}
    \toprule
    \textbf{Tehnologie} & \textbf{Familie} & \textbf{Sec.\ transversală BRAM [cm\textsuperscript{2} / bit]} & \textbf{Sec.\ transversală CRAM [cm\textsuperscript{2} / bit]} & \textbf{FIT/Mb BRAM} & \textbf{FIT/Mb CRAM}\\
    \midrule
    28 nm & Artix-7 & \(6.32 \times 10^-15\) & \(6.99 \times 10^-15\) & 72 & 74 \\
    28 nm & Kintex-7 & \(5.57 \times 10^-15\) & \(5.69 \times 10^-15\) & 42 & 40 \\
    20 nm & UltraScale & \(4.43 \times 10^-15\) & \(2.55 \times 10^-15\) & 58 & 32 \\
    16 nm & UltraScale+ & \(9.82 \times 10^-16\) & \(2.67 \times 10^-16\) & 15 & 5 \\
    \bottomrule
  \end{tabular}
\end{table}

Secțiunea transversală este definită ca probabilitatea ca o particulă energetică să producă un \gls{see}, cum ar fi un \gls{seu} sau un latch-up, și se exprimă în \(cm^2/bit\) sau \(cm^2/dispozitiv\). De asemenea, un Failure in Time (FIT) corespunde unei defecțiuni la un miliard de ore de funcționare a dispozitivului. Cu cât secțiunea transversală este mai mare, cu atât \gls{fpga}-ul este mai sensibil la radiație, ceea ce implică creșterea numărului de erori și, implicit, numărul de FIT-uri. În contextul aplicației curente, acest aspect este însă favorabil. Se poate observa că familia Artix-7 este, în medie, de zece ori mai sensibilă la radiație decât familia US+, ceea ce permite o detecție mai eficientă a particulelor energetice.

\subsection{Analiză a consumului de energie}
Un alt aspect esențial în alegerea dispozitivului este consumul de energie. Pentru a evalua acest parametru, s-a folosit o versiune preliminară a programului dedicat detecției \gls{seu}-urilor, prezentat în~\cite{isetc} și descris în detaliu în Capitolul”\ref{seu_program_implementation}. Programul populează 100 de blocuri \gls{bram} cu un șablon cunoscut de valori, apoi le scanează secvențial pentru a detecta eventualele bit-flip-uri cauzate de radiație. Testarea s-a realizat folosind trei variante ale aceluiași proiect, rulat la frecvențele de 10 MHz, 50 MHz și 100 MHz, pentru a observa dependența între consumul dinamic de energie și frecvența de operare. Simularea consumului de energie a fost realizată folosind unealta integrată de estimare a puterii din cadrul AMD Vivado 2024.1, pentru cele mai performante \gls{fpga}-uri din fiecare dintre cele trei familii analizate: Artix-7, Artix US+ și Kintex US+. Rezultatele sunt prezentate în Figura~\ref{fig:fpga_power_estimations}, precum și în~\cite{jes}. Chiar dacă au fost folosiți aceiași parametri de intrare și aceleași constrângeri pentru toate simulările, se poate observa un consum static de 4.4 ori mai mic pentru dispozitivul XC7A200T, față de celelalte două \gls{fpga}-uri. Deși consumul său dinamic este cu aproximativ 15\% mai ridicat, \gls{fpga}-ul Artix-7 este cel mai eficient din punct de vedere energetic, ceea ce reprezintă un argument în plus pentru alegerea acestui dispozitiv.

\begin{figure}[h]
    \centering
    \begin{tikzpicture}
        \begin{groupplot}[
            ybar,
            /pgf/bar width=16pt,
            enlarge x limits=0.22,
            enlarge y limits=0.3,
            ylabel={Putere [mW]},
            symbolic x coords={100 MHz, 50 MHz, 10 MHz},
            xtick=data,
            width=8.5cm,
            height=7cm,
            grid=major,nodes near coords,
            tick label style={font=\footnotesize},
            every node near coord/.append style={font=\footnotesize},
            legend style={at={(1.1,-0.2)}, anchor=north, legend columns=3, column sep=7pt},
            group style={group size=2 by 1,horizontal sep=1cm,ylabels at=edge left,vertical sep=0pt}
        ]
        
        % First plot
        \nextgroupplot[title={Consum static}]
        \addplot+[blue, fill=blue!20] coordinates {(100 MHz,  103)(50 MHz,  103)(10 MHz, 102)};
        \addlegendentry{XC7A200T}
        \addplot+[red, fill=red!20] coordinates {(100 MHz,  457)(50 MHz,  455)(10 MHz, 453)};
        \addlegendentry{AU25P}
        \addplot+[brown, fill=brown!20] coordinates {(100 MHz,  457)(50 MHz,  455)(10 MHz, 453)};
        \addlegendentry{KU5P}
        
        % Second plot
        \nextgroupplot[title={Consum dinamic}]
        \addplot+[blue, fill=blue!20] coordinates {(100 MHz,  626)(50 MHz,  366)(10 MHz, 159)};
        \addplot+[red, fill=red!20] coordinates {(100 MHz,  473)(50 MHz,  291)(10 MHz, 140)};
        \addplot+[brown, fill=brown!20] coordinates {(100 MHz,  475)(50 MHz,  290)(10 MHz, 140)};
        
        \end{groupplot}
    \end{tikzpicture}
    \caption{Consumul de energie pentru FPGA-urile din cele trei familii.}%
\label{fig:fpga_power_estimations}
\end{figure}

\section{Structura generală a proiectului Verilog}
\label{sw_general_structure}
Întregul proiect destinat implementării detectorului de \gls{seu}-uri, precum și al sistemelor de comunicație externă și auxiliare, a fost dezvoltat în limbajul Verilog și este ilustrat în Figura~\ref{fig:sw_general_diagram}. Dezvoltarea acestor module a fost realizată folosind AMD Vivado 2024.1, iar pentru proiectele de test bazate pe procesorul MicroBlaze au fost utilizate programele AMD Vivado 2024.2 și AMD Vitis 2024.2. Verilog, la fel ca celelalte limbaje de descriere hardware, se bazează pe module individuale ce îndeplinesc o funcție specifică, conectate între ele prin semnale de diverse lățimi. Diagrama prezentată în Figură evidențiază modulul Top, care, după cum sugerează și denumirea, reprezintă modulul de nivel superior, care încapsulează restul blocurilor funcționale. În centrul diagramei se află modulul \gls{du}, responsabil cu instanțierea tuturor elementelor de detecție, stocarea erorilor identificate într-un buffer intern de tip \gls{fifo}, precum și inserarea manuală de erori prin cele patru fire INJ.\@ Această interfață are un rol esențial atât în simularea corectă a programului, cât și în lipsa unei surse de radiație ionizantă în laborator, care ar permite testarea \gls{fpga}-ului în condiții reale de iradiere. Semnalele INJ sunt generate de blocul \gls{vio}, un \gls{ip} oferit de Xilinx care permite interfațarea directă cu un calculator prin intermediul interfeței \gls{jtag}. Acest bloc suportă atât semnale de intrare, cât și de ieșire, facilitând injectarea de erori și observarea comportamentului sistemului în timpul testelor.

\begin{figure}[h!]
    \centering
    
    \caption{Schema bloc a modulului Top scris în Verilog.}%
\label{fig:sw_general_diagram}
\end{figure}

Sub blocul \gls{du} se află \gls{ip}-ul \gls{sem}, folosit pentru scanarea automată a memoriei \gls{cram}, identificarea și clasificarea severității erorilor detectate, precum și corectarea acestora acolo unde este posibil. Acest modul este esențial pentru menținerea \gls{fpga}-ului într-o stare funcțională cât mai mult timp posibil și pentru a identifica cât mai multe erori, astfel crescând eficiența întregului detector (\gls{fpga}-ul ales având de 5.7 ori mai multă memorie de configurare decât memoria \gls{bram}). Implementarea și testarea sa sunt detaliate în Capitolul~\ref{sem}

Începerea unui ciclu de scanare a memoriilor \gls{bram} și \gls{cram} se face cu ajutorul unui timer implementat cu redundanță \gls{tmr}, activat la intervale predefinite. Frecvența acestuia este presetată de utilizator și trebuie să fie suficient de mare pentru a asigura detecția rapidă a erorilor, precum și stocarea acestora într-un buffer pentru transmiterea către \gls{obc}. Sub timer se regăsește generatorul de ceas, un circuit proprietar Xilinx care preia un semnal de ceas extern și îl convertește într-un semnal stabil, cu frecvența programabilă. Se pot observa două semnale de intrare, provenite de la oscilatorul \gls{lvds} ce se folosește de o interfață diferențială, precum și trei semnale de ieșire. Acestea sunt identice din punct de vedere al frecvenței și fazei, și sunt folosite în paralel la implementarea sistemului \gls{tmr}. Folosirea a trei semnale de ceas independente scade posibilitatea apariției unor erori datorate interferențelor electrice apărute din cauza radiației.

În colțul din dreapta sus a imaginii este prezent un registru \gls{tmr} responsabil de detectarea evenimentelor de tip brown-out și transmiterea acestora către \gls{obc}. Acesta este inițializat cu valoarea \enquote{1} și este resetat la valoarea \enquote{0} după prima tranzacție 
\gls{spi}. În contextul unui nanosatelit, un brown-out apare atunci când satelitul se reorientează și alocă toată energia electrică disponibilă sistemelor de control al atitudinii, reducând semnificativ alimentarea modulelor experimentale. Astfel, se pot pierde toate erorile de tip \gls{seu} acumulate în \gls{fifo} care nu au fost transmise către \gls{obc} și stocate într-o memorie non-volatilă.

Comunicația cu \gls{obc}-ul este realizată prin modulul \gls{spi} situat în partea dreaptă a diagramei. Acesta, la inițializarea unei tranzacții (prin activarea semnalului \gls{cs}), încarcă toate datele de interes (prin firele SEU, STATUS și altele) într-un shift register și le transmite serial prin linia \gls{miso}. Deoarece comunicația este unidirecțională (de la \gls{fpga} către \gls{obc}), linia \gls{mosi} poate fi reutilizată pentru programarea cipului de memorie flash ce stochează fișierele de configurare ale \gls{fpga}-ului. Astfel se poate implementa abilitatea de a reprograma \gls{fpga}-ul în spațiu, fără necesitatea unui calculator conectat prin interfața \gls{jtag}. Acest lucru se poate face simultan și fără conflicte electrice, deoarece fiecare dintre cele două sisteme comunică doar într-o singură direcție. Pentru a putea interconecta pinii \gls{io} de la cipul flash cu cei ai interfeței \gls{lvds} \gls{spi}, este necesară conversia între protocoalele \gls{lvds} și Low-Voltage CMOS 3.3V (LVCMOS33). Aceasta este realizată automat în mare parte de \gls{fpga}, cu ajutorul bufferelor de tip OBUFDS și IBUFDS oferite de Xilinx~\cite{7series_select_io}, care transformă un semnal diferențial de ieșire sau de intrare, în semnale single-ended. Apare o problemă, însă, la conectarea pinului de ceas destinat cipului flash. Acesta este un pin de configurare special al \gls{fpga}-ului și nu poate fi controlat direct prin folosirea unei constrângeri obișnuite. Pentru a putea transmite semnale către acest pin după etapa de configurare a \gls{fpga}-ului, este necesară instanțierea primitivei STARTUPE2. Această primitivă facilitează accesul utilizatorului la semnale interne critice ale \gls{fpga}-ului, de exemplu semnalele globale de reset și ceas, precum și pinii externi de status~\cite{ug953}.

\section{Arhitectura și implementarea elementului detector}%
\label{seu_program_implementation}

Principiul de funcționare al modulului \acrfull{du} constă în scanarea simultană a unui număr de memorii \gls{bram} și \gls{lutram}, și compararea valorilor stocate cu un șablon de referință, cu scopul de a detecta bit-flip-uri cauzate de evenimentele de tip \gls{seu}. Memoriile \gls{bram} disponibile în familia Artix-7 sunt de tip dual port și au o capacitate de 36 Kb, ce poate fi configurată în diferite formate. În~\cite{isetc} au fost prezentate motivele alegerii dimensiunii de 2048 de adrese cu o lățime de 18 biți per cuvânt. 

Pentru a fundamenta această alegere, au fost testate toate configurațiile posibile de \gls{bram} într-un proiect simplificat, cu structura asemănătoare modulului \gls{du}. În cadrul testelor, s-a măsurat consumul de resurse pentru fiecare variantă, iar rezultatele au fost preluate și ilustrate în Tabelul~\ref{tab:sw_bram_aspect_ratios}. Din aceste date se poate observa faptul că numărul de \gls{lut}-uri și \gls{ff}-uri crește odată cu lățimea unui cuvânt, iar viteza de scanare a fiecărui bloc \gls{bram} scade de două ori la fiecare înjumătățire a spațiului de adrese. Configurația 2048 $\times$ 18 reprezintă un compromis optim între rata de scanare și utilizarea eficientă a resurselor logice, păstrând un spațiu de adrese suficient de mare, fără a crește drastic numărul de \gls{lut}-uri. Valorile scrise în memorie sunt alcătuite dintr-o succesiune de biți '1' și '0' pentru adresele pare, iar inversul acestora pentru adresele impare. Astfel se asigură o distribuție echilibrată de biți \enquote{1} și \enquote{0}, ceea ce contribuie la omogenizarea memoriei și permite detectarea uniformă a bit-flip-urilor produse de \gls{seu}-uri.

\begin{table}[h!]
  \centering
  \renewcommand{\arraystretch}{1.3}
  \caption{Utilizarea resurselor de către DE pentru toate dimensiunile BRAM.}%
  \label{tab:sw_bram_aspect_ratios}
  \begin{tabular}{L{2cm} C{1.65cm} C{1.65cm} C{1.65cm} C{1.65cm} C{1.65cm} C{1.65cm} C{1.65cm}}
    \toprule
    \textbf{Raport} & \textbf{512 $\times$ 72} & \textbf{1K $\times$ 36} & \textbf{2K $\times$ 18} & \textbf{4K $\times$ 9} & \textbf{8K $\times$ 4}  & \textbf{6K $\times$ 2} & \textbf{2K $\times$ 1}\\
    \midrule
        \textbf{LUT-uri} & 246 & 173 & 134 & 122 & 116 & 124 & 128 \\
        \textbf{FF-uri} & 342 & 246 & 204 & 189 & 186 & 192 & 201 \\
        \textbf{Dim. [Kb]} & 36 & 36 & 36 & 36 & 36 & 32 & 32 \\
    \bottomrule
  \end{tabular}
\end{table}

În cazul programului prezentat în~\cite{isetc}, au fost utilizate doar 100 de blocuri de memorie \gls{bram} pentru evaluarea consumului de energie și de resurse, diminuând astfel timpul necesar pentru sintetizarea și implementarea fiecărei versiuni a programului. În cadrul proiectului de față, însă, se dorește utilizarea a numărului maxim de memorii pentru maximizarea performanței senzorului de radiație. Astfel, au fost instanțiate 356 de memorii \gls{bram} dintr-un total de 365 disponibile pe \gls{fpga}. Blocurile rămase au fost alocate altor componente esențiale, precum modulul \gls{sem}, sisteme de test (Debug Hub, Integrated Logic Analyzer (ILA)\cite{ug908}), sau un procesor MicroBlaze. În plus, au fost implementate și blocuri de memorie identice cu cele \gls{bram}, folosind primitive \gls{lutram}. Acestea au dimensiunea de 128 de adrese cu o lățime a cuvântului de 1 bit, însă au fost aranjate pentru a permite o dimensiune parametrizabilă. Numărul maxim de astfel de instanțe este 40, iar detaliile privind implementarea lor sunt prezentate în Capitolul~\ref{lutram}.

\subsection{Detector Unit (DU)}
Modulul \acrfull{du} integrează toată logica necesară pentru detectarea erorilor cauzate de \gls{seu}-uri. Acesta include instanțierea memoriilor de detecție, scanarea ciclică a acestora, memorarea numărului de cicluri efectuate, identificarea erorilor de tip bit-flip, stocarea acestora într-un buffer \gls{fifo} și transmiterea lor către blocul de comunicație \gls{spi}. Schema bloc a modulului este ilustrată în Figura~\ref{fig:sw_du_general_diagram} și va fi detaliată în continuare. 

\begin{figure}[h!]
    \centering
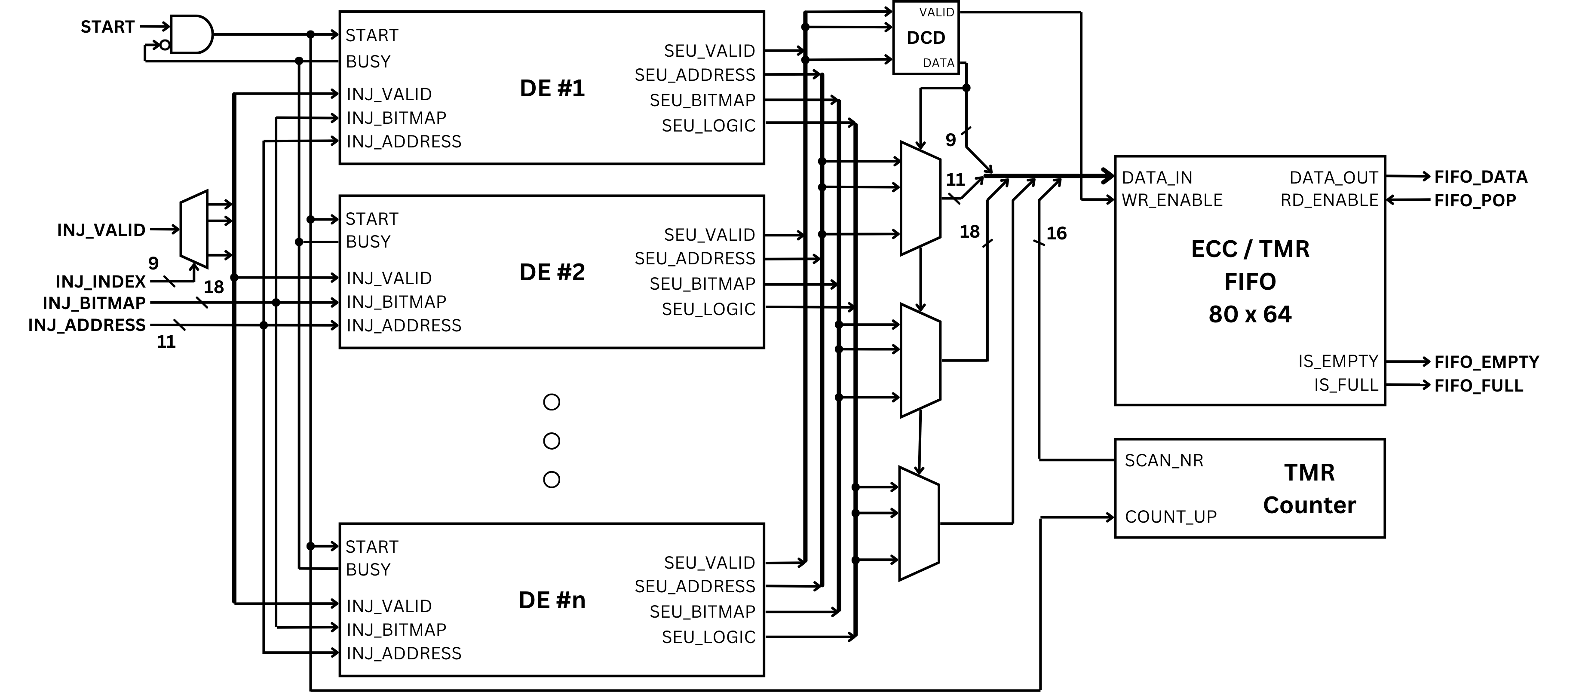
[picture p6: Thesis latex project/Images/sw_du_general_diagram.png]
    
    \caption{Schema bloc a modulului Detector Unit (DU).}%
\label{fig:sw_du_general_diagram}
\end{figure}

Este instanțiat un număr parametrizabil de module \gls{de}, fiecare având două semnale de control, trei intrări pentru injectarea de erori (INJ) și patru ieșiri pentru raportarea acestora (SEU). Semnalele de control sunt intrarea START și ieșirea BUSY, legate între ele pentru a preveni inițierea unei noi scanări înainte de finalizarea celei curente, protejând astfel logica de detecție. Semnalul FIFO\_POP provine din modulul \gls{spi} și este activat la inițierea fiecărei tranzacții între \gls{fpga} și \gls{obc}. Acesta are rolul de a extrage datele din \gls{fifo} și de a reseta contorul de cicluri. 

Cele trei intrări INJ reprezintă adresa de inserare a erorii, valoarea acesteia și semnalul de enable. Acestea sunt comune tuturor instanțelor \gls{de}, cu excepția semnalului de enable, care este activ doar dacă semnalul INJ\_INDEX corespunde indexului detectorului respectiv. Ieșirile fiecărui \gls{de} sunt formate din adresa erorii, valoarea citită, un semnal de activare și un semnal suplimentar SEU\_LOGIC, utilizat pentru identificarea erorilor combinaționale. Acest ultim semnal indică faptul că la unul dintre registrele protejate prin \gls{tmr} a apărut o neconcordanță în valorile stocate. Circuitul specific și modul de funcționare sunt detaliate în Capitolul~\ref{tmr}. 

Pentru a permite localizarea în timp a evenimentelor \gls{seu} (și în spațiu, dacă se cunosc date adiționale plăcii \gls{aicors}), a fost integrat un contor special de 16 biți, protejat prin redundanță \gls{tmr}, care numără ciclurile de la ultima tranzacție \gls{spi}. Contorul se incrementează la activarea semnalului START și este resetat la activarea semnalului FIFO\_POP, iar valoarea acestuia este atașată fiecărui eveniment detectat și stocată în bufferul \gls{fifo}.

Semnalele de activare de la fiecare \gls{de} sunt concatenate și inserate într-un codificator prioritar, care determină indexul detectorului care a identificat \gls{seu}-ul. Acest index este apoi utilizat ca semnal de selecție pentru o matrice de multiplexoare, menită să selecteze semnalele de adresă, valoare și \gls{seu} logic, de la detectorul care a identificat evenimentul \gls{seu}. Toate aceste informații, împreună cu numărul ciclului în care s-a detectat eroarea, sunt stocate într-un buffer \gls{fifo} cu o adâncime de 256 de poziții și o lățime de 55 de biți. Această lățime corespunde sumei lățimilor fiecărui semnal: 9 biți pentru indexul detectorului, 11 biți de adresă, 18 biți de date, un bit pentru \gls{seu} logic și 16 biți pentru timestamp.

Formele de undă asociate unui ciclu de funcționare a modulului \gls{du} sunt ilustrate în Figura~\ref{fig:sw_de_waveforms}. Se observă inserarea a trei erori prin intermediul firelor INJ, urmată de începerea secvenței de scanare prin aplicarea unui impuls pe semnalul start. Semnalul busy se activează, iar contorul de adrese din fiecare modul \gls{de} începe să incrementeze valorile, până când atinge limita superioară de 2047. La atingerea acestei limite, se resetează, marcând finalul ciclului de scanare. În timpul acestui proces, erorile injectate sunt detectate, iar coordonatele acestora, împreună cu numărul ciclului la care au fost descoperite, sunt stocate în bufferul \gls{fifo}.

\begin{figure}[h!]
    \centering
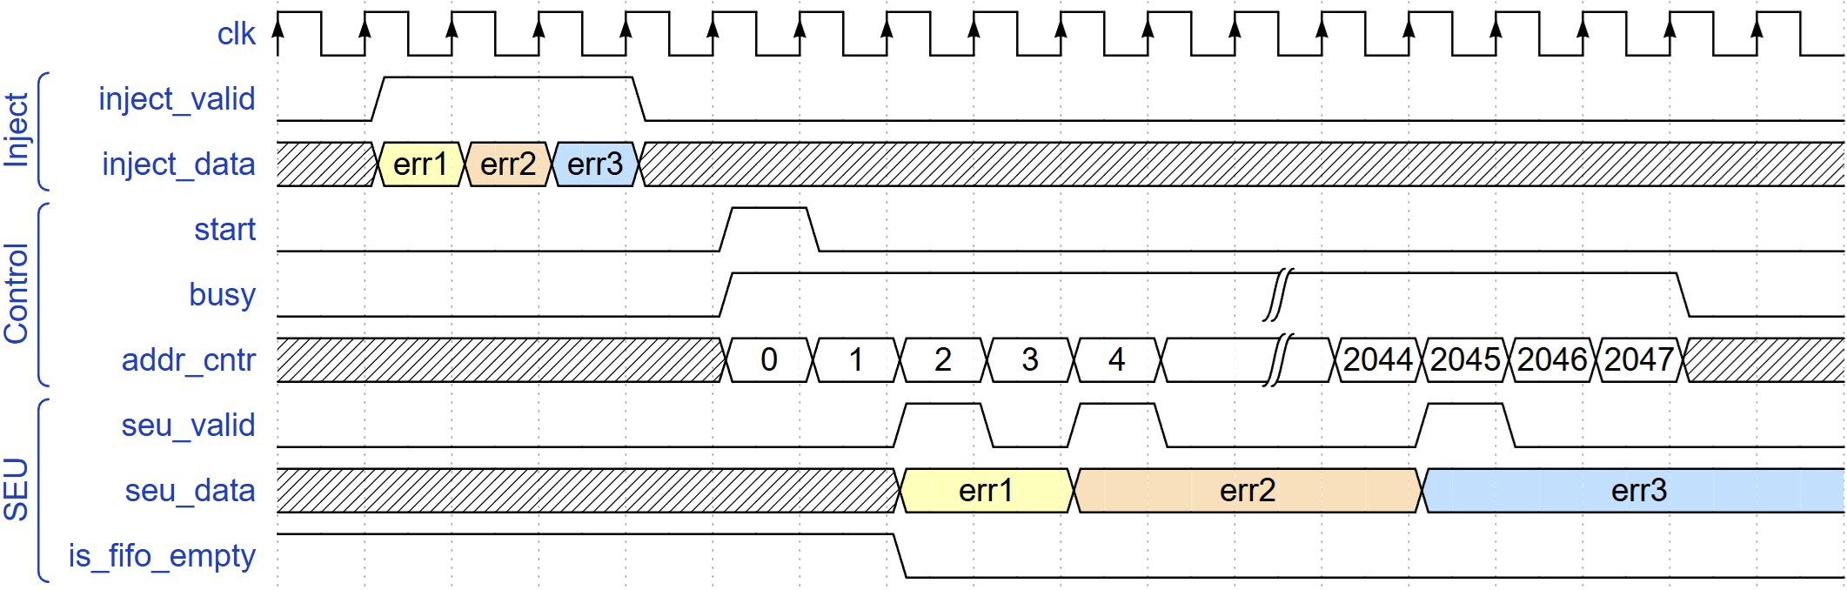
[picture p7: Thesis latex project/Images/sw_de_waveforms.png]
    
    \caption{Formele de undă ce exemplifică funcționarea modulului DU.}%
\label{fig:sw_de_waveforms}
\end{figure}

\subsection{Detector Element (DE)}
Modulul \acrfull{de} este alcătuit din trei componente principale: un contor de adrese protejat prin \gls{tmr}, o unitate de memorie (realizată fie cu \gls{bram}, fie cu \gls{lutram}) și modulul de monitorizare (Monitor), responsabil cu detecția erorilor de tip bit-flip. Diagrama acestui modul este prezentată în Figura~\ref{fig:sw_de_general_diagram} și este similară cu cea propusă în~\cite{isetc}, cu excepția integrării logicii de inserare a erorilor. La activarea semnalului START, contorul \gls{tmr} începe să incrementeze valoarea adresei, care este transmisă simultan către portul B al memoriei și către modulul Monitor. În timpul procesului de scanare, dacă se detectează neconcordanțe între registrele din sistemele \gls{tmr} (în contor sau în Monitor), semnalul SEU\_LOGIC este activat. Acesta se obține dintr-o poartă OR aplicată asupra semnalelor provenite de la fiecare registru protejat, iar rezultatul este stocat într-un registru, pentru a putea fi transmis odată cu primul \gls{seu} detectat.

Modulul Monitor, având la dispoziție atât adresa memoriei, cât și valoarea de la adresa respectivă, poate determina dacă a avut loc un bit-flip cauzat de \gls{seu}, printr-un set de operații logice simple. În cazul afirmativ, se activează semnalul SEU\_VALID și sunt transmise semnalele relevante prin firele SEU.\@ Concomitent, valoarea afectată din memorie este corectată prin portul A, folosind adresa curentă și valoarea așteptată (aleasă în funcție de paritatea adresei).

\begin{figure}[h!]
    \centering
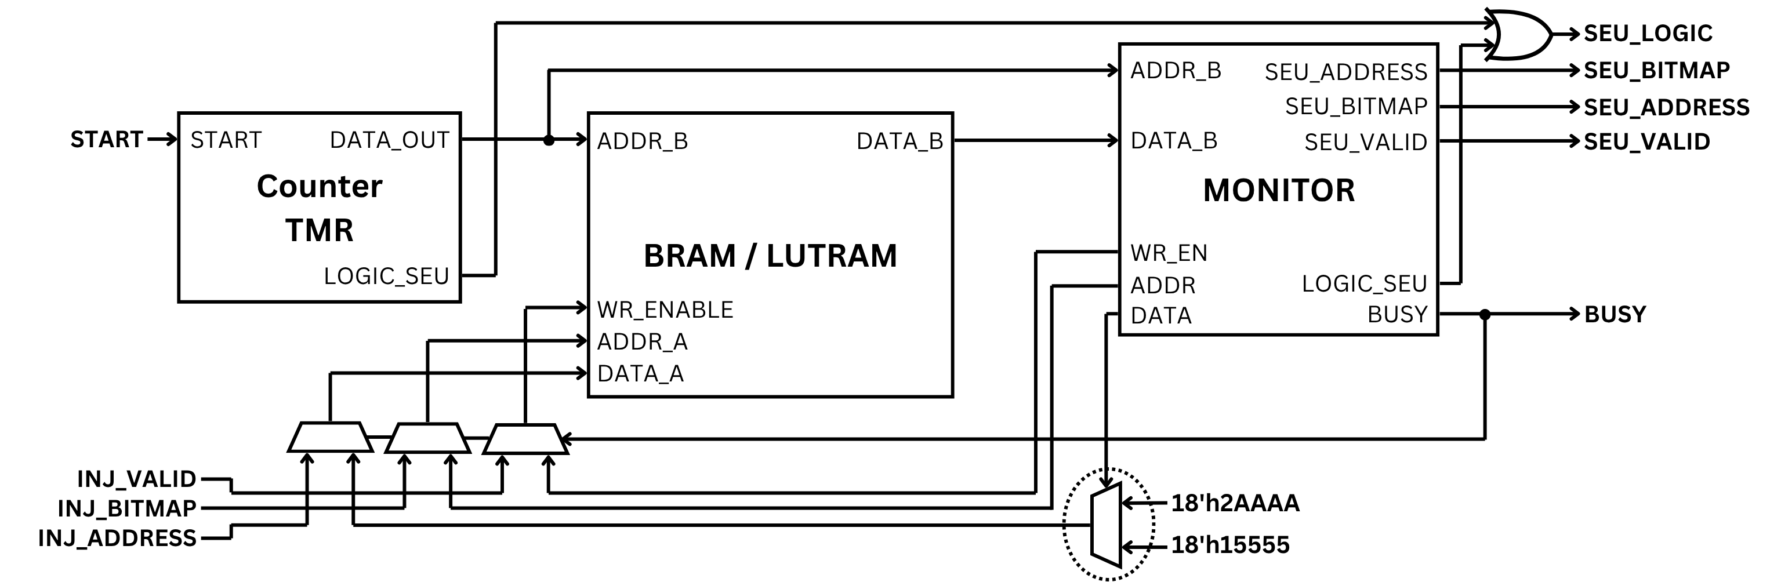
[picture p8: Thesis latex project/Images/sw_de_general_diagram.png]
    
    \caption{Schema bloc a modulului Detector Element (DE).}%
\label{fig:sw_de_general_diagram}
\end{figure}

Inserarea erorilor se face tot prin portul A al memoriei, dar numai atunci când modulul \gls{de} nu se află într-un ciclu de scanare. Dacă semnalul BUSY este \enquote{1}, cele trei multiplexoare din colțul stânga jos al diagramei selectează semnalele provenite din modulul Monitor, care are prioritate pentru a corecta eventualele erori detectate în timpul scanării. În schimb, dacă semnalul BUSY este \enquote{0}, aceleași multiplexoare aleg semnalele INJ, permițând scrierea intenționată a unor valori eronate în memorie.

\subsection{LUTRAM}%
\label{lutram}
După cum s-a menționat anterior, memoriile de tip \gls{bram} nu reprezintă singurele structuri dintr-un \gls{fpga} capabile să stocheze date. Pe lângă acestea, AMD oferă posibilitatea generării automate a blocurilor \gls{fifo} (acestea utilizând însă tot \gls{bram}-uri~\cite{ug473}), iar dispozitivele din familiile UltraScale și UltraScale+ dispun și de memorie \gls{uram}. De asemenea, \gls{ff}-urile prezente în număr mare pot reține valori, dar capacitatea lor este prea mică, iar utilizarea lor pentru stocare ar crește semnificativ complexitatea unei implementări, fără un câștig proporțional în performanța senzorului. Cea mai bună alternativă la memoria \gls{bram} rămâne memoria distribuită \gls{lutram}.

În arhitectura hardware, un \acrfull{lut} reprezintă o simplificare a implementării funcțiilor logice prin pre-calcularea rezultatelor posibile și stocarea acestora într-un tabel de adevăr. În funcție de intrare, \gls{lut}-ul oferă valoarea de ieșire corespunzătoare, rapid și cu o latență redusă. În majoritatea \gls{fpga}-urilor moderne, \gls{lut}-urile sunt construite cu celule \gls{sram}, celule care pot fi reutilizate pentru implementarea unor memorii \gls{ram} de dimensiuni mici cu o latență foarte scăzută. Denumirea de memorie distribuită provine din faptul că aceste celule \gls{lut}-uri sunt dispersate relativ uniform în întregul dispozitiv \gls{fpga}.

AMD pune la dispoziție mai multe primitive \gls{lutram} de dimensiuni și tipuri variate~\cite{ug953}. În cadrul acestui proiect, a fost aleasă primitiva RAM128X1D, o memorie \gls{ram} de 128 de adrese pe un singur bit. Deși există și primitive cu o capacitate mai mare (256 de valori), RAM128X1D a fost aleasă datorită interfeței dual-port necesară pentru a replica fidel comportamentul unei memorii \gls{bram}. Pentru a ajunge la dimensiuni comparabile cu cele ale unui \gls{bram}, sunt concatenate mai multe primitive \gls{lutram} atât în serie, cât și în paralel, obținându-se astfel o memorie mai mare și mai ușor de integrat în locul unui \gls{bram} standard.

O variantă simplificată a codului sursă utilizat pentru generarea unei memorii cu dimensiuni parametrizabile, având aceeași interfață ca un \gls{bram} dual-port, este prezentată în Figura~\ref{fig:sw_lutram_code}. Codul conține două bucle for: prima buclă instanțiază primitivele în serie, crescând spațiul de adrese, iar a doua în paralel, crescând lățimea cuvântului. Alegerea atentă a intervalelor de biți (la liniile 23, 25 și 28) asigură implementarea corectă a logicii de multiplexare necesară pentru conectarea instanțelor \gls{lutram}. Pentru a imita cu acuratețe un \gls{bram}, au fost introduși regiștrii de pipeline pentru ieșire, iar valorile de inițializare (INIT) sunt setate prin folosirea parametrilor INIT\_A și INIT\_B, reglați pentru a genera secvențele binare alternante \enquote{1}-\enquote{0} sau \enquote{0}-\enquote{1}.

\begin{figure}[h!]
\begin{lstlisting}[language=Verilog]
module lut_ram #(
    parameter WIDTH =           18     ,
    parameter DEPTH =           2048   ,
) (
    input                       clka   ,                      
    input                       wea    ,   
    input [$clog2(DEPTH)-1 : 0] addra  , 
    input [WIDTH-1 : 0]         dina   ,                 
    input [$clog2(DEPTH)-1 : 0] addrb  ,  
    output [WIDTH-1 : 0]        doutb
);

wire [WIDTH-1 : 0] read_data [(DEPTH/128)-1 : 0];
assign doutb <=    read_data [addrb_d];

generate
    for (j = 0; j < DEPTH/128; j = j + 1) begin : gen_bank
        for (i = 0; i < WIDTH; i = i + 1) begin : gen_lutram
        RAM128X1D #(
           .INIT    ({64{INIT_B[i], INIT_A[i]}})
        ) RAM128X1D_inst (
           .WCLK    (clka                                   ), 
           .WE      (wea & (addra[$clog2(DEPTH)-1 : 7] == j)),
           .A       (addra[7-1 : 0]                         ),        
           .D       (dina[i]                                ),    
           .SPO     (                                       ),
           .DPRA    (addrb[7-1 : 0]                         ),  
           .DPO     (read_data[j][i]                        )       
        );
        end
    end
endgenerate
endmodule
\end{lstlisting}
\caption{Codul simplificat al modulului care instanțiază primitivele LUTRAM.}%
\label{fig:sw_lutram_code}
\end{figure}

Acest modul a fost supus simulării pentru a confirma comportamentul dorit, iar ulterior a fost sintetizat și implementat. Resursele logice utilizate pentru o instanță a modulului sunt prezentate în Tabelul~\ref{tab:sw_lutram_utilization}. După cum se poate deduce și analitic, numărul de \gls{lutram}-uri utilizate este 1152, rezultat din înmulțirea a 16 memorii în serie, 18 în paralel și 4 memorii pentru fiecare instanță de 128 de adrese. Numărul ridicat de multiplexoare este justificat de necesitatea concatenării instanțelor \gls{lutram}, însă, având în vedere că restul proiectului utilizează un număr redus de multiplexoare, acest aspect nu ar trebui să afecteze scalabilitatea proiectului.

\begin{table}[h!]
  \centering
  \renewcommand{\arraystretch}{1.3}
  \caption{Utilizarea resurselor pentru o instanță a modulului LUTRAM.}%
  \label{tab:sw_lutram_utilization}
  \begin{tabular}{L{4cm} C{2.05cm} C{2.05cm} C{2.05cm} C{2.05cm} C{2.05cm}}
    \toprule
    \textbf{Tip} & \textbf{FF-uri} & \textbf{LUT-uri} & \textbf{LUTRAM} & \textbf{Muxuri F7} & \textbf{Muxuri F8}\\
    \midrule
        \textbf{Disponibile pe FPGA} & 269200 & 134600 & 46200 & 67300 & 33650 \\
        \textbf{Modulul LUTRAM} & 40 & 80 & 1152 & 612 & 18 \\
    \bottomrule
  \end{tabular}
\end{table}

Numărul maxim de module se determină prin împărțirea numărului total de resurse de tip \gls{lutram} disponibile la numărul de \gls{lutram}-uri necesare pentru o instanță. În urma acestui calcul, rezultă 40 de blocuri de dimensiuni echivalente cu cele \gls{bram}, ce pot fi inserate direct în locul modulelor \gls{bram} pentru a crește numărul de elemente de detecție a radiației. Totuși, folosirea intensă a memoriei distribuite impune o provocare semnificativă uneltelor de sintetizare și implementare, care nu reușesc să respecte constrângerile de tip hold. Această limitare a fost depășită prin aplicarea unei strategii alternative de sintetizare, denumită Flow\_AlternateRoutability, ce utilizează un set optimizat de algoritmi pentru eficientizarea rutabilității și pentru reducerea numărului de multiplexoare utilizate~\cite{ug901}.

\section{Tehnici de protecție împotriva radiației}
Problema implementării unui senzor de radiație folosind un dispozitiv \gls{fpga} constă chiar în caracteristica esențială care permite realizarea acestuia: sensibilitatea la radiație. Acest \enquote{avantaj și dezavantaj} determină apariția de erori de tip \gls{seu} nu doar în memoriile de detecție, unde sunt intenționate și utile, ci și în restul elementelor logice ale dispozitivului, de la registre individuale \gls{ff}, până la memoria de configurare a \gls{fpga}-ului. Din acest motiv, apare nevoia utilizării unor tehnici adiționale de protecție pentru acele circuite și componente în care un bit-flip compromite funcționarea corectă a sistemului.

Tehnicile discutate în acest capitol acoperă mai multe niveluri: de la protejarea componentelor individuale, precum memoria \gls{cram} sau registrele, la metode generale de protecție împotriva erorilor, cum ar fi \gls{ecc} și \gls{crc}, până la strategii de protejare a întregului dispozitiv \gls{fpga}, prin reprogramarea acestuia cu un proiect redundant, în cazul unei configurații compromise.

\subsection{Protejarea memoriei de configurare a FPGA-ului}%
\label{sem}
\gls{ip}-ul oferit de AMD pentru monitorizarea și corectarea erorilor apărute în memoria de configurare a dispozitivelor \gls{fpga} poartă denumirea \acrfull{sem}~\cite{pg036}. În cadrul proiectului de față, acest modul a fost utilizat în paralel cu blocul \gls{du}, cu scopul de a extinde zona sensibilă a detectorului (și implicit, performanța) și de a crește fiabilitatea dispozitivului prin protejarea memoriei \gls{cram}.\@ \gls{ip}-ul \gls{sem} reprezintă doar blocul de control, responsabil cu gestionarea datelor primite de la două primitive externe. Pentru buna lui funcționare, acesta a fost încapsulat într-un modul ajutător care implementează aceste primitive și oferă o interfață simplificată, care poate fi integrată mai ușor în restul proiectului.

Principalele primitive utilizate în combinație cu controller-ul \gls{sem} sunt ICAP și FRAME\_ECC, fiecare având o interfață dedicată pe controller. Primitiva ICAP permite accesul utilizatorului la registrele și circuitele de configurare ale \gls{fpga}-ului, iar FRAME\_ECC monitorizează automat circuitele de corecție de erori \gls{ecc} și \gls{crc} din memoria de configurare.\@ \gls{cram}-ul este structurat într-o matrice de frame-uri, fiecare cu un cod \gls{ecc},  în timp ce întregul ansamblu este protejat de un cod global \gls{crc}. În combinație, aceste primitive permit identificarea erorilor apărute la anumite coordonate din memoria \gls{cram} și corectarea lor prin modificarea valorilor stocate, un mecanism similar cu cel utilizat în modulul \gls{du} pentru corectarea erorilor din \gls{bram}-uri.

Interfața modulului rezultat este prezentată în Figura~\ref{fig:sw_sem_interface_code}. Aceasta conține cele trei semnale de ceas identice (folosite pentru sistemele \gls{tmr}), un semnal de reset,  un contor pe 16 biți al erorilor identificate de la pornirea sistemului, o interfață de monitorizare (\textit{status}) și una pentru inserare de erori (\textit{inject}). Controller-ul \gls{sem} funcționează ca o mașină de stări finite, indicând starea curentă prin activarea unuia dintre semnalele \textit{status}, cu excepția semnalului \textit{status\_heartbeat}, care generează impulsuri periodice în timpul stării de monitorizare. Acesta poate fi folosit în implementarea unui watchdog timer, pentru a verifica dacă \gls{ip}-ul funcționează corect și dacă se află în starea activă de operare.

Interfața inject oferă o metodă de comunicație rudimentară ce permite controlul direct al primitivei ICAP și inserarea manuală de erori în memoria \gls{cram}. Pe lângă aceasta, mai există interfața monitor, bazată pe protocolul \gls{uart}, care permite o metodă mai robustă de a comunica cu modulul \gls{sem}. Aceasta a fost însă exclusă pentru a reduce complexitatea modulului și din cauza lipsei unei interfețe \gls{uart} robuste pe nanosatelit.

Interfața inject utilizează semnalul \textit{inject\_address}, cu o lățime de 40 de biți, pentru trimiterea comenzilor dorite, și \textit{inject\_strobe} pentru confirmarea trimiterii unei comenzi. Prin această interfață se pot trimite două tipuri de comenzi: schimbarea stării mașinii de stări finite (prin codarea celor mai semnificativi patru biți ai adresei) sau inserarea de erori specifice, prin specificarea coordonatelor frame-ului, cuvântului și bitului afectat. În plus, semnalul \textit{inject\_forced\_start} a fost introdus pentru a readuce controller-ul în starea de monitorizare în urma unei erori necorectabile (acesta întrerupând scanarea în cazul unei astfel de erori).

\begin{figure}[ht!]
\begin{lstlisting}[language=Verilog]
module sem_wrapper(
  input         clk_iA                ,
  input         clk_iB                ,
  input         clk_iC                ,
  input         reset_i               ,
  
  output        status_heartbeat      ,
  output        status_initialization ,
  output        status_observation    ,
  output        status_correction     ,
  output        status_classification ,
  output        status_injection      ,
  output        status_essential      ,
  output        status_uncorrectable  ,
  
  output [15:0] error_counter         ,
  
  input         inject_strobe         ,
  input [39:0]  inject_address        ,
  input         inject_forced_start
);
\end{lstlisting}
\caption{Interfața modulului Verilog SEM.}%
\label{fig:sw_sem_interface_code}
\end{figure}

Diagrama de stări și tranziții a acestui modul este ilustrată în Figura~\ref{fig:sw_sem_fsm}, evidențiind relația dintre diferitele stări ale mașinii de stări finite. Se observă că modulul trece printr-o fază de inițializare, unde se aduce într-o stare cunoscută, urmată automat de trecerea în starea \textit{observation}, în care se realizează scanarea continuă a memoriei \gls{cram}. La detectarea unei erori, \gls{ip}-ul  \gls{sem} trece obligatoriu prin stările de \textit{correction} și \textit{classification}, indiferent dacă aceste opțiuni au fost selectate ca funcționalități la crearea \gls{ip}-ului. Tranziția prin starea \textit{correction} la fiecare eroare detectată este utilizată și pentru incrementarea contorului \textit{error\_counter}. Acest comportament este independent de natura erorii, fie ea corectabilă sau necorectabilă, ceea ce permite o contorizare robustă a \gls{seu}-urilor apărute. După starea \textit{classification}, în funcție de tipul erorii detectate, se activează semnalul \textit{essential} dacă eroarea afectează o zonă utilizată a memoriei de configurare, respectiv semnalul \textit{uncorrectable}, în cazul în care eroarea a fost identificată, dar nu poate fi corectată din anumite motive.

\begin{figure}[h!]
    \centering
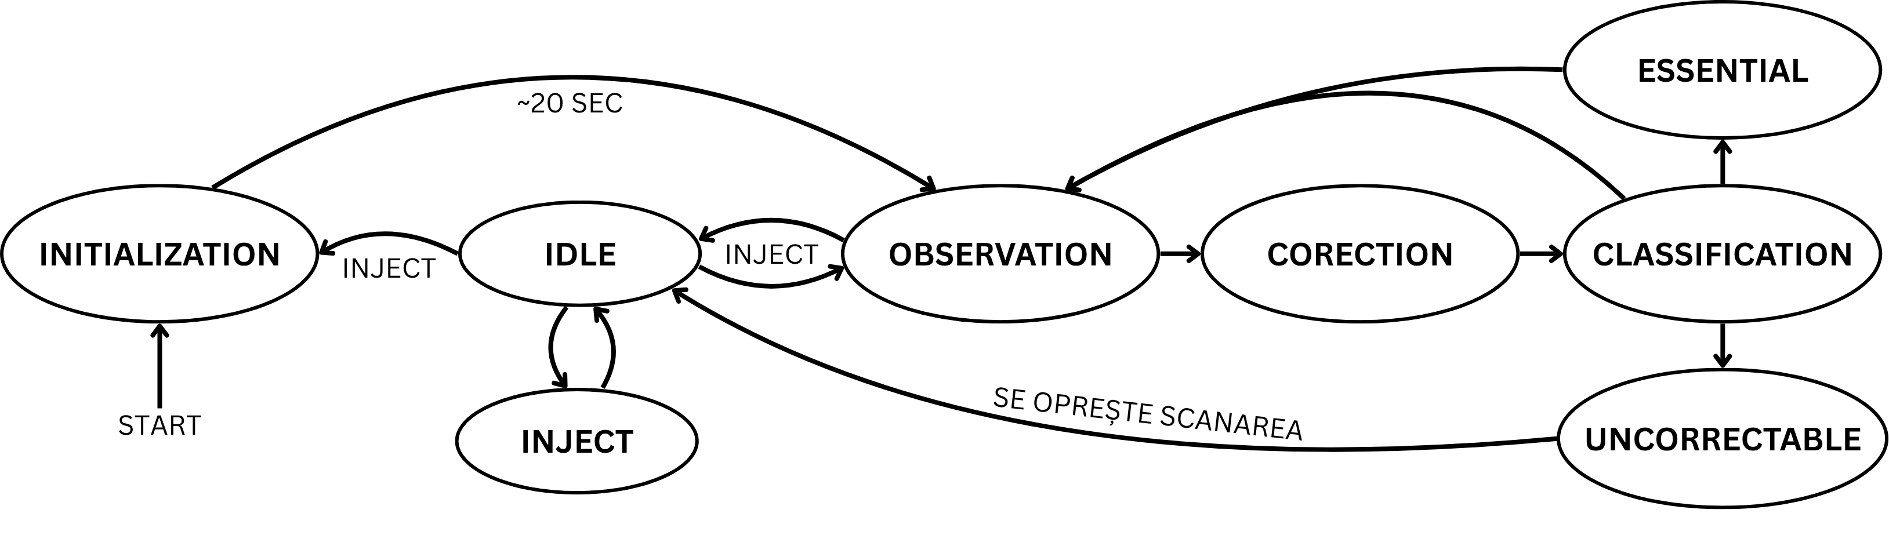
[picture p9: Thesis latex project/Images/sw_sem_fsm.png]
    
    \caption{Diagrama de stări și tranziții a IP-ului SEM.}%
\label{fig:sw_sem_fsm}
\end{figure}

Din această Figură reiese că, în cazul identificării unei erori necorectabile, controller-ul iese din starea de scanare automată și intră în starea \textit{idle}, unde rămâne blocat până la reinițializarea modulului și corectarea erorii, sau până la primirea unei comenzi specifice pe interfața inject. Pentru a evita această întrerupere, a fost introdus semnalul suplimentar \textit{inject\_forced\_start}, care forțează trecerea din starea \textit{idle} în starea \textit{observation}, reluând astfel scanarea. 

La crearea \gls{ip}-ului pot fi alese mai multe setări și funcționalități diferite, în funcție de scopurile proiectului. Au fost selectate opțiunile de injectare și corectare de erori, iar frecvența de operare a fost aliniată cu cea a restului sistemului. Metoda de corecție de erori aleasă a fost \textit{Enhanced Repair}, care combină codurile \gls{ecc} și \gls{crc} pentru a putea detecta două erori și a corecta una. Deși există o variantă superioară, \textit{Replace}, care presupune înlocuirea frame-ului corupt cu o copie stocată extern, aceasta a fost exclusă din lipsa unei memorii redundante. În final, resursele utilizate de acest modul includ 8.5 memorii \gls{bram} și 26 de memorii \gls{lutram}, un preț mic de plătit în raport cu avantajele semnificative aduse în ceea ce privește integritatea și eficiența sistemului.

\subsection{Triple Modular Redundancy (TMR)}%
\label{tmr}
Conceptul de \gls{tmr} a fost introdus de Von Neumann în~\cite{neumann_book_tmr}, unde propune utilizarea unui \enquote{organ de majoritate} care, pe baza a trei semnale provenite din surse logice identice, identifică și corectează eventualele erori apărute pe una dintre ramuri, îmbunătățind astfel fiabilitatea generală a sistemului. Această idee a fost extinsă semnificativ de IBM în~\cite{ibm_paper_tmr}, prin implementarea practică a unui circuit de vot majoritar combinațional, cu cele trei intrări provenite din elemente secvențiale redundante. Autorii concluzionează că \gls{tmr} este o metodă excelentă de creștere a fiabilității prin redundanță logică, atâta timp cât este utilizată cu moderație și nu înlocuiește complet alte tehnici de detectare și corectare a erorilor.

În cadrul acestui proiect, noțiunea de \gls{tmr} a fost implementată prin realizarea a două module similare: TMR\_register și TMR\_register\_simple, codul simplificat al celui din urmă fiind ilustrat în Figura~\ref{fig:sw_tmr_register_code}. Diferența dintre cele două constă în prezența unui reset sincron configurabil în modulul TMR\_register, în plus față de reset-ul asincron, prezent în ambele variante. Aceste module au fost utilizate oriunde a fost necesară implementarea unui registru, iar semnalele de detecție a erorilor generate de aceste module au fost concatenate printr-o poartă OR și memorate într-un pachet de date din modulul \gls{du}.

Ideea generală constă în replicarea unui registru în trei instanțe identice, fiecare având același semnal de intrare, semnal de activare și semnal de reset, dar având ceasuri diferite. Ieșirile celor trei registre sunt evaluate de două circuite de vot majoritar: unul pentru selectarea semnalului de ieșire (activ dacă cel puțin două dintre registre conțin aceeași valoare --- linia 32), iar celălalt pentru detectarea unei posibile erori, prin identificarea unei diferențe între cele trei semnale (linia 33). Pentru a preveni optimizarea automată a acestor registre de către unealta de sintetizare, fiecare \gls{ff} este protejat prin atributul \textit{DONT\_TOUCH=\enquote{true}}, iar blocul \textit{generate} este necesar datorită creării de \gls{ff}-uri diferite în funcție de frontul semnalului de reset.

\begin{figure}[ht!]
\begin{lstlisting}[language=Verilog]
(* DONT_TOUCH=\enquote{true} *) reg[SIGNAL_WIDTH - 1 : 0] sgn_A;
(* DONT_TOUCH=\enquote{true} *) reg[SIGNAL_WIDTH - 1 : 0] sgn_B;
(* DONT_TOUCH=\enquote{true} *) reg[SIGNAL_WIDTH - 1 : 0] sgn_C;

generate
    always @(posedge clk_iA or posedge reset_i) begin 
        if (reset_i)
            sgn_A <= #TP {SIGNAL_WIDTH {1'b0}};
        else if (true_condition_i)
            sgn_A <= #TP signal_in;
        else
            sgn_A <= #TP signal_out;
    end  
    always @(posedge clk_iB or posedge reset_i) begin
        if (reset_i)
            sgn_B <= #TP {SIGNAL_WIDTH {1'b0}};
        else if (true_condition_i)
            sgn_B <= #TP signal_in;
        else
            sgn_B <= #TP signal_out;
    end  
    always @(posedge clk_iC or posedge reset_i) begin
        if (reset_i)
            sgn_C <= #TP {SIGNAL_WIDTH {1'b0}};
        else if (true_condition_i)
            sgn_C <= #TP signal_in;
        else
            sgn_C <= #TP signal_out;
    end
endgenerate

signal_o = (sgn_B & sgn_A) | (sgn_A & sgn_C) | (sgn_C & sgn_B);
seu_o = (~sgn_B & sgn_A) | (~sgn_A & sgn_C) | (~sgn_C & sgn_B);
\end{lstlisting}
\caption{Conținutul simplificat al modulului Verilog TMR\_register\_simple.}%
\label{fig:sw_tmr_register_code}
\end{figure}

Modulele rezultate au la fel de multe intrări și ieșiri ca un registru standard, menținând un nivel mare de flexibilitate. Acestea includ trei parametri pentru a configura aspecte ca: frontul activ al semnalului de reset, lățimea semnalului de date și o valoare de reset configurabilă, disponibilă în modulul mai avansat. Logica combinațională necesară este implementată eficient prin două \gls{lut}-uri (pentru un semnal de intrare de un bit) și este ușor scalabilă, iar numărul de \gls{ff}-uri, deși triplu față de un registru normal, crește liniar cu dimensiunea semnalului de date. Variante de redundanță extinsă, cu cinci sau șapte elemente logice, au fost luate în considerare, dar au fost considerate prea costisitoare pentru avantajele marginale aduse.

\subsection{Coduri detectoare sau corectare de erori}
Prima mențiune a unor astfel de coduri \gls{ecc} în logica digitală a fost făcută de Richard Hamming în~\cite{hamming_book_ecc}, unde propune inserarea unor biți de paritate în poziții specifice ale unui cuvânt (la puteri ale lui 2), pentru a permite detectarea și corectarea erorilor de un singur bit. Mai târziu, acest cod Hamming a fost extins în varianta \gls{secded} prin adăugarea unui bit global de paritate la finalul cuvântului, permițând astfel corectarea unei erori și detectarea a două erori. Pentru acest proiect, a fost utilizată această variantă extinsă, în situațiile în care era necesară o metodă adițională de protejare pe lângă \gls{tmr}. Codurile \gls{crc} au fost considerate, dar neavând abilitatea de a corecta erori, nu au fost implementate activ, ci au fost utilizate sub forma instanțelor deja integrate în \gls{fpga} (în memoria \gls{cram} și în funcționalitatea \gls{fpga} MultiBoot). Alte tipuri avansate de coduri \gls{ecc}, precum cele BCH, Reed-Solomon sau Turbo, nu au fost luate în considerare din cauza complexității ridicate și a gradului de protecție exagerat pentru aplicația curentă.

Principalele locuri unde codul \gls{ecc} a fost folosit sunt în cadrul \gls{fifo}-urilor și în procesul de transmitere a pachetelor de date către \gls{obc}. Pentru a evita implementarea unei logici separate pentru fiecare instanță de utilizare a acestor coduri, s-a optat pentru utilizarea \gls{ip}-ului \gls{ecc} oferit de AMD, care implementează automat logica de codare sau decodare \gls{secded}, pentru orice lățime a cuvântului între 4 și 64 de biți. Numărul minim de biți de paritate este determinat automat folosind relația \(2^r \geq n + r + 1\), unde \textit{r} este numărul de biți de paritate Hamming, iar \textit{n} reprezintă numărul de biți de date, cu un bit suplimentar adăugat la final.

Deoarece triplicarea unui întreg \gls{fifo} ar fi prea costisitoare, s-a ales codificarea datelor la intrare și decodificarea acestora la ieșire, înainte de a fi transmise mai departe. Astfel se asigură protejarea pe întreaga durată de stocare a datelor și se creează semnale de indicare a erorilor, care pot fi concatenate cu semnalele SEU\_LOGIC descrise anterior. De asemenea, deoarece pachetele de date transmise către \gls{obc} conțin anumite spații libere, utilizate pentru alinierea datelor la multipli de 8 biți (structura pachetelor fiind descrisă în Capitolul~\ref{spi}), se pot introduce coduri checksum pentru valorile individuale din aceste pachete, oferind un strat adițional de protecție în timpul transmisiei. Codificarea este realizată pe \gls{fpga} cu ajutorul unui algoritm XOR, iar decodificarea este efectuată pe \gls{obc} de către microprocesorul principal, printr-un algoritm scris în C.

\subsection{FPGA MultiBoot}
Pentru anumite interfețe de configurare ale unui \gls{fpga} Xilinx, precum \gls{spi} folosit în cadrul acestui proiect, poate fi activată o funcționalitate specială care permite \gls{fpga}-ul să încarce un nou fișier de configurare în cazul în care cel inițial devine corupt. Acest mecanism, denumit MultiBoot, se bazează pe detecția erorilor prin codurile \gls{crc} integrate în fiecare fișier bitstream și se activează prin adăugarea unor comenzi specifice în fișierul de constrângeri ale proiectului~\cite{xapp1247}. De obicei, MultiBoot este folosit pentru a asigura existența unui proiect de rezervă, cunoscut ca fiind funcțional, care poate fi încărcat în cazul în care bitstream-ul principal conține erori de implementare sau funcționale. Totodată, această funcționalitate este relevantă și în contextul protecției împotriva radiației cosmice, care poate corupe configurația \gls{fpga}-ului.

Procesul presupune generarea a două fișiere bitstream identice, dintre care unul conține opțiunile suplimentare BITSTREAM.\allowbreak\ CONFIG.\allowbreak\ CONFIGFALLBACK, care activează funcția MultiBoot, și BITSTREAM.\allowbreak\ CONFIG.\allowbreak\ NEXT\_\allowbreak\ CONFIG\_\allowbreak\ ADDR care indică adresa din memoria externă unde este stocat bitstream-ul de rezervă. Ulterior, se execută o comandă tcl specială, care combină cele două bitstream-uri într-un singur fișier binar pentru programarea cipului de memorie. În urma acestei comenzi, bitstream-ul principal este plasat la adresa 0, iar cel de rezervă la adresa specificată, restul memoriei fiind umplut cu valori nule. 

În momentul pornirii, \gls{fpga}-ul începe configurarea cu bitstream-ul de la adresa 0. Dacă este detectată o eroare \gls{crc}, se face trecerea la bitstream-ul de rezervă. O opțiune suplimentară care reduce șansele de apariție a unor erori este BITSTREAM.\allowbreak\ GENERAL.\allowbreak\ COMPRESS, care comprimă fișierele de configurare de până la zece ori. Un fișier mai mic reduce probabilitatea ca o particulă cosmică să altereze un bit important. Aceste metode au fost testate cu succes pe \gls{fpga}, trecerea la bitstream-ul de rezervă fiind realizată prin coruperea deliberată a fișierului principal.

\section{Modulele de comunicație}
Dispozitivul \gls{fpga} detaliat în capitolele anterioare are, pe lângă funcționalitatea principală de a detecta bit-flip-uri cauzate de \gls{seu}-uri, și rolul de a comunica și monitoriza alte componente, aflate atât pe plăcuța \gls{aicors}, cât și pe \gls{pcb}-ul cu \gls{obc}. Pentru a îndeplini această funcție, au fost dezvoltate și implementate mai multe module Verilog care asigură compatibilitate cu diferite protocoale de comunicație, necesare interacțiunii cu fiecare dispozitiv în parte. Principalele interfețe vizate sunt: \gls{uart}, folosită de modulul \gls{sem} pentru raportarea erorilor detectate, \gls{i2c}, pentru monitorizarea senzorilor de curent de pe \gls{pcb}, și \gls{lvds} \gls{spi}, responsabilă de transmiterea pachetelor de date relevante către \gls{obc}. Aceste module vor fi prezentate și analizate în capitolele următoare, cu excepția modulului \gls{uart}, care nu a mai fost integrat în versiunea finală a proiectului.

Modulul \gls{uart} implementa cele două canale de comunicație (transmisie și recepție) prin intermediul a două registre de shiftare, completate cu logică auxiliară și mai multe setări parametrizabile, precum: tipul de paritate, frecvența de ceas de intrare, frecvența de transmisie, ordinea biților în cadrul cuvântului transmis și dimensiunea filtrului de zgomot aplicat datelor de intrare. Acest modul a fost conectat la interfața Monitor a blocului \gls{sem}, prezentat în Capitolul~\ref{sem}, pentru testarea funcționalității acestuia. Cu toate acestea, având în vedere absența unei interfețe \gls{uart} între \gls{fpga} și \gls{obc}, interfața Monitor nu a mai fost utilizată, iar modulul \gls{uart} nu a fost inclus în configurația finală și, prin urmare, nu va fi detaliat în continuare.

\subsection[Inter-Integrated Circuit (I2C)]{Inter-Integrated Circuit (I\textsuperscript{2}C)}
Protocolul \gls{i2c}, patentat inițial de NXP Semiconductors~\cite{patent_i2c}, este o interfață serială de comunicație cu două fire, unul de ceas (SCL) și unul de date (SDA), folosită pentru transmisii de viteză redusă între un procesor și circuite integrate auxiliare. Viteza maximă de transmisie a datelor este limitată la 5 Mb/s din cauza naturii open-drain a liniilor SCL și SDA, care, deși oferă robustețe, nu permit un timp de creștere suficient de rapid din cauza constantei de timp RC asociate capacității parazite a \gls{pcb}-ului și a rezistenței de pull-up de pe fiecare linie. Pe o magistrală \gls{i2c} există un singur dispozitiv de control, denumit master, și mai multe dispozitive auxiliare (slave), fiecare identificabil printr-o adresă unică. În multe cazuri, aceste adrese pot fi setate prin conectarea unor pini speciali la VCC sau la GND.\@ În cadrul proiectului, acest protocol este utilizat de patru senzori de curent INA219, prezenți pe \gls{pcb}-ul \gls{aicors}, dar și cu un \gls{io} Expander integrat pe a doua versiune a plăcii, care conectează diferite semnale de status la \gls{fpga}.

Modulul dezvoltat are rol de master și este bazat pe o mașină de stări finite (FSM) care controlează secvența necesară pentru transmiterea unui pachet de date \gls{i2c}. Formele de undă asociate unui astfel de pachet sunt prezentate în Figura~\ref{fig:sw_i2c_waveforms}, iar diagrama de stări a FSM-ului este ilustrată în Figura~\ref{fig:sw_i2c_fsm}. Interfața modulului include o pereche de trei semnale pentru controlul celor două \gls{fifo}-uri de la intrare și ieșire, precum și cele două linii specifice protocolului \gls{i2c}, direcționate către doi pini \gls{io} ai \gls{fpga}-ului. Aceste semnale sunt transmise prin două buffere tri-state, pentru a implementa starea de înaltă impedanță caracteristică magistralei \gls{i2c}. Modulul integrează și logica de arbitrare, esențială pentru a da controlul magistralei unui singur dispozitiv și pentru a-i permite să comunice, în funcție de ordinea inițierii transmisiunii.

FSM-ul menționat conține patru stări principale: \textit{LD\_ADDR}, care încarcă adresa dispozitivului țintă și un bit care indică tipul tranzacției curente ca una de citire sau scriere. \textit{RD\_DATA} și \textit{WR\_DATA} realizează citirea sau scrierea de date în funcție de bitul de comandă, iar \textit{ACK\_NACK}, intermediar între celelalte stări, gestionează semnalele de Acknowledge și Not Acknowledge, care sunt de lățimea unui bit și care provin de la dispozitivul care transmite date la momentul respectiv. Există câte un semnal ACK după adresă și după fiecare opt biți transmiși, pentru a asigura că dispozitivul receptor este prezent și primește mesajele, iar odată ce se întâlnește un semnal NACK, tranzacția se oprește. Pe lângă acestea, stările IDLE, START și STOP asigură tranzițiile corecte în parcurgerea FSM-ului, iar starea WAIT a fost introdusă pentru a preveni inițierea unei noi tranzacții în cazul în care o transmisie este deja în curs sau dacă s-a detectat o coliziune pe magistrală.

\vspace{0.7em}
\begin{figure}[h!]
    \centering
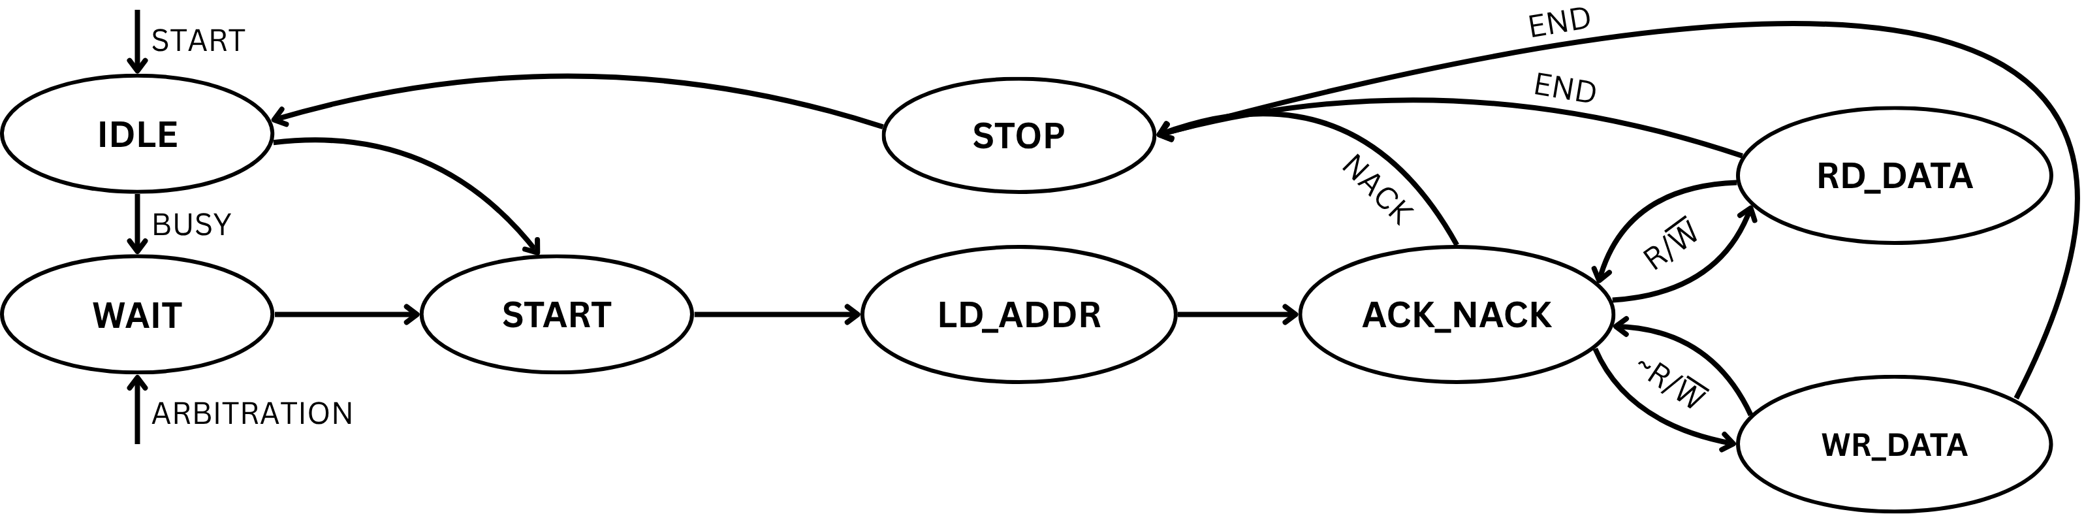
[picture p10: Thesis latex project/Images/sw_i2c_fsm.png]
    
    \caption{Diagrama de stări și tranziții a modulului I2C.}%
\label{fig:sw_i2c_fsm}
\end{figure}

Formele de undă care asociază stările FSM-ului cu etapele unei transmisii \gls{i2c} sunt prezente în partea de sus a Figurii~\ref{fig:sw_i2c_waveforms}. Se observă starea IDLE cât timp nu există activitate pe magistrală, START, inițiat prin coborârea semnalului SDA înainte de SCL, și STOP prin ridicarea lui SCL înainte de SDA.\@ În cadrul stării LD\_ADDR se transmit cei 7 biți de adresă (sau opțional 10 biți de adresă, configurabil printr-un parametru din modul), urmați de bitul R/$\overline{\mbox{W}}$. După fiecare octet transmis urmează starea ACK/NACK, pentru confirmarea recepției. De asemenea, se mai poate observa că semnalul de ceas este evaluat pe frontul negativ. Acest aspect este esențial în protocolul \gls{i2c}, pentru a reduce întârzierile de propagare și zgomotul, în care datele sunt transmise de emițător pe frontul negativ al ceasului, și sunt citite de receptor pe frontul pozitiv.

\begin{figure}[ht!]
    \centering
    
    \vskip 1em
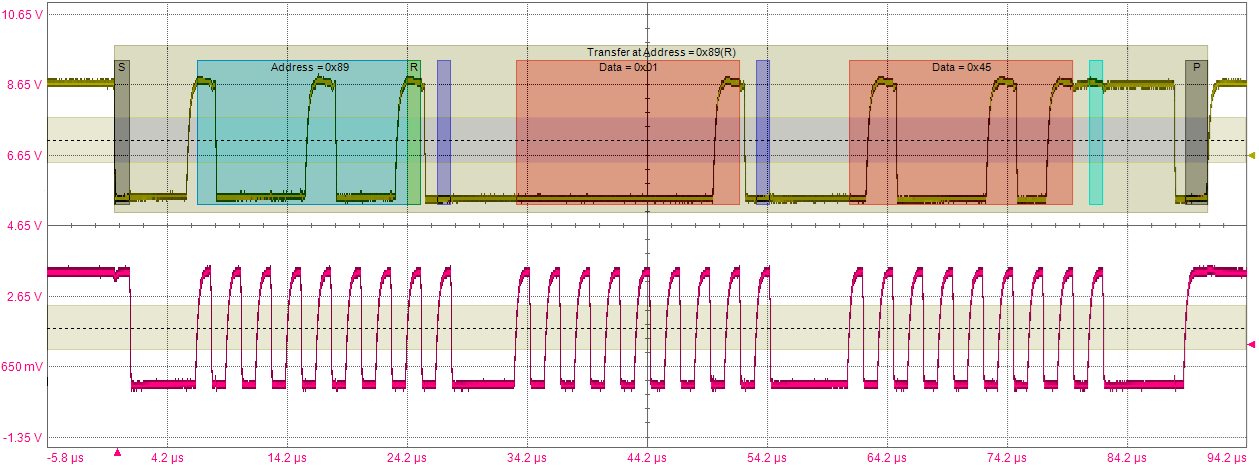
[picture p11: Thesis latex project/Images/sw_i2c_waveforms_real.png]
    
    \caption{Formele de undă ce exemplifică funcționarea modulului I2C.}%
\label{fig:sw_i2c_waveforms}
\end{figure}

Acest modul a fost testat cu succes în comunicații bidirecționale, atât cu senzorii de curent de pe placa \gls{aicors}, cât și cu o memorie \gls{eeprom} aflată pe placa de test Nexys Video. În cazul senzorilor de curent, au fost scrise registrele de configurare și calibrare, iar ulterior au fost citite cele care stochează valorile de tensiune, curent și putere măsurate, fiecare dintre acestea având o lățime de 16 biți. O astfel de tranzacție, capturată cu un osciloscop Teledyne Lecroy, este ilustrată în jumătatea de jos a Figurii~\ref{fig:sw_i2c_waveforms}. Tranzacția respectivă implică citirea registrului de curent de la senzorul cu adresa 0x44, transformată în 0x89 după adăugarea bitului R/$\overline{\mbox{W}}$. Comunicarea a avut loc la o frecvență de 140 kHz, cu 40 kHz peste limita specificată pentru modul standard al interfeței. Se poate observa un timp de ridicare semnificativ al semnalelor (aproximativ 400 ns), care limitează creșterea vitezei de transmisie fără a schimba caracteristici hardware ale magistralei. Cu toate acestea, modulul a funcționat stabil și fără erori până la 1 MHz, frecvență la care timpul de ridicare a semnalului a depășit semi-perioada ceasului.

Interfața modulului include, pe lângă câte trei semnale de acces al  \gls{fifo}-urilor (semnal de date, semnal de validare și un semnal de status \gls{fifo}: plin pentru transmitere și gol pentru recepție), și alte semnale și parametrii de interes. Semnalele de control, start și busy, au roluri intuitive, iar adresa este transmisă separat de bitul R/$\overline{\mbox{W}}$, pentru a simplifica logica de control. Un semnal suplimentar indică numărul de octeți dintr-o tranzacție. Parametrii configurabili ai modulului includ: dimensiunea adresei (7 sau 10 biți), dimensiunea \gls{fifo}-urilor și frecvențele ceasurilor de intrare și de transmisie. Acești ultimi parametri sunt folosiți pentru configurarea divizorului de ceas integrat, responsabil cu generarea frecvenței mai reduse necesare logicii de transmisie și recepție. Comunicarea între cele două domenii de ceas, cel rapid al sistemului (de până la 100  MHz) și cel lent al magistralei (până la 1 MHz), este gestionată prin intermediul blocurilor \gls{fifo}, care asigură decuplarea corectă a celor două frecvențe.

\subsection{Serial Peripheral Interface (SPI)}%
\label{spi}
Interfața \gls{spi} este similară cu interfața \gls{i2c} din multe puncte de vedere, ambele fiind utilizate pentru comunicații seriale pe distanțe scurte între dispozitive master și slave. Totuși, diferențele principale dintre ele oferă interfeței \gls{spi} o eficiență și performanță superioare. Spre deosebire de magistrala \gls{i2c}, care folosește două fire, \gls{spi} utilizează cel puțin patru: două pentru transmiterea datelor în ambele direcții (uneori pot fi combinate într-un singur semnal, reducând protocolul la half-duplex), un fir pentru semnalul de ceas și câte un fir individual pentru selecția fiecărui dispozitiv slave. Astfel, se elimină necesitatea alocării de adrese dispozitivelor și permite transferul simultan de date bidirecțional. În plus, interfața utilizează semnale de tip push-pull, spre deosebire de open-drain din \gls{i2c}, permițând viteze de transfer mai mari, cu frecvențe de până la 50 MHz. Această interfață este utilizată pentru comunicația dintre placa \gls{aicors} și modulul \gls{obc} al nanosatelitului, printr-o variantă diferențială, \gls{lvds} \gls{spi}, care asigură o rezistență sporită la zgomot.

Spre deosebire de modulul \gls{i2c}, dezvoltat ca fiind master, modulul \gls{spi} din \gls{fpga}-ul \gls{aicors} este implementat ca slave, fiind semnificativ mai simplu și activat doar la comanda \gls{obc}-ului. Diagrama funcțională a acestui modul este prezentată în Figura~\ref{fig:sw_spi_general_diagram}. Semnalul de start al modulului este transmis de către \gls{obc} prin firul \gls{cs}, iar datele sunt transferate prin semnalul \gls{miso} și printr-un buffer OBUFDS, semnalul \gls{mosi} nefiind utilizat, deoarece modulul este destinat doar pentru transmitere (acesta este totuși utilizat pentru a scrie date în memoria flash a plăcii). Semnalele \gls{cs} și \gls{sck} trec prin buffere IBUFDS, care le convertesc din semnale diferențiale în semnale single-ended, iar apoi printr-o serie de \gls{ff}-uri, inserate toate într-un bloc de comparație pentru a implementa un detector de front. Această metodă bazată pe registre de deplasare este folosită pentru a crea un filtru adițional împotriva zgomotului prezent pe magistrală. Detectoarele de front rezultate conduc atât logica internă de încărcare și deplasare a registrului de shiftare care gestionează datele transmise, cât și semnalele de stare, precum semnalul busy.

\begin{figure}[h!]
    \centering
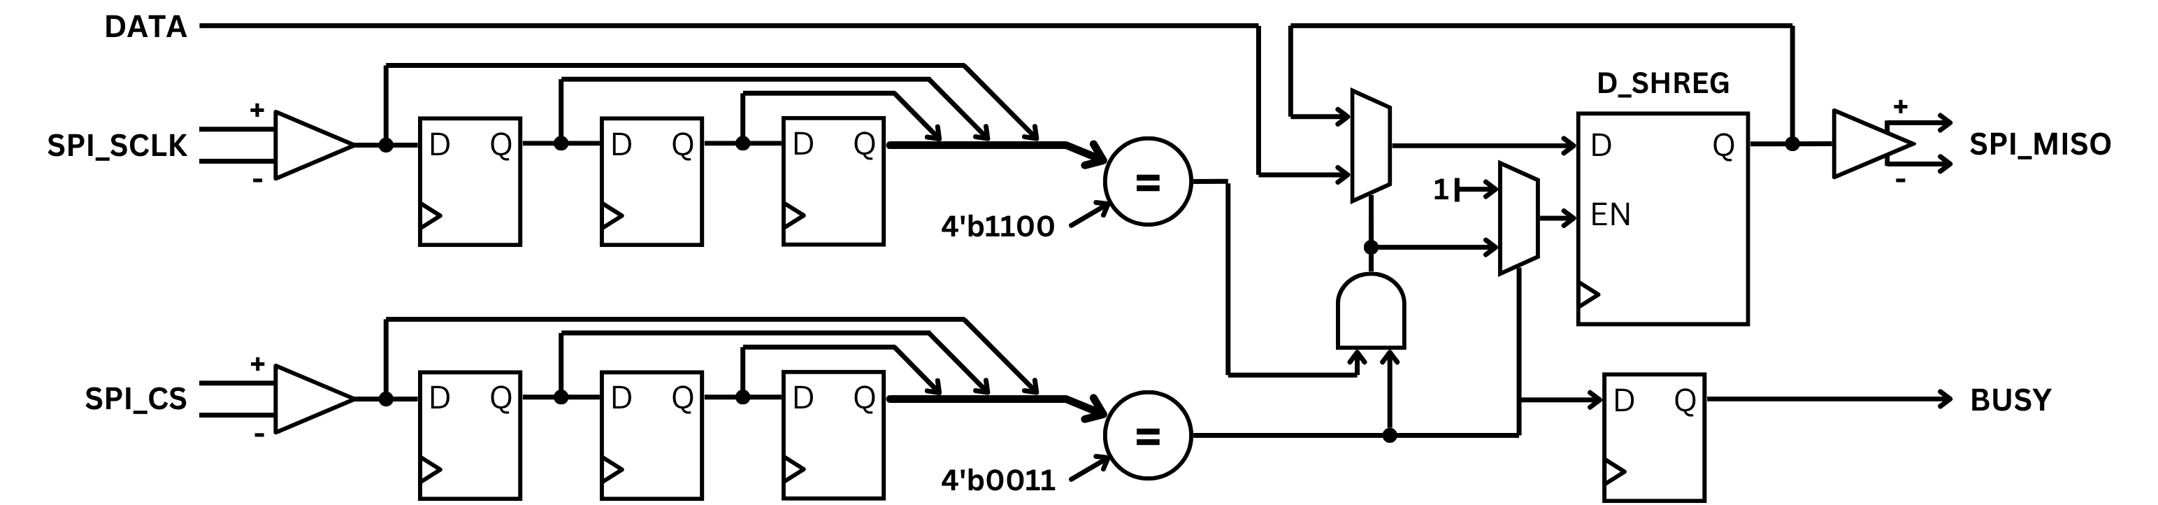
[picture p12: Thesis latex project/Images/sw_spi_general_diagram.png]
    
    \caption{Schema bloc a modulului Verilog SPI.}%
\label{fig:sw_spi_general_diagram}
\end{figure}

Acest modul funcționează la frecvențe ale magistralei de cel puțin zece ori mai mici decât frecvența de ceas a sistemului și este configurabil printr-o serie de parametri, precum: dimensiunea filtrelor de zgomot, dimensiunea pachetului de date și ordinea transmiterii sale (MSB-first sau LSB-first), precum și modul de funcționare \gls{spi}. Cele patru moduri standardizate sunt determinate de combinațiile între polaritatea (CPOL) și faza (CPHA) semnalului de ceas, care determină fronturile de eșantionare și transmitere a datelor. Funcționalitatea modulului a fost verificată cu succes, prin transmiterea unor pachete de date de test către un Arduino Due. O astfel de tranzacție este prezentată în Figura~\ref{fig:sw_spi_waveforms_real}, unde, de sus în jos, sunt ilustrate semnalele \gls{cs}, \gls{sck} și \gls{miso}.

\begin{figure}[ht!]
    \centering
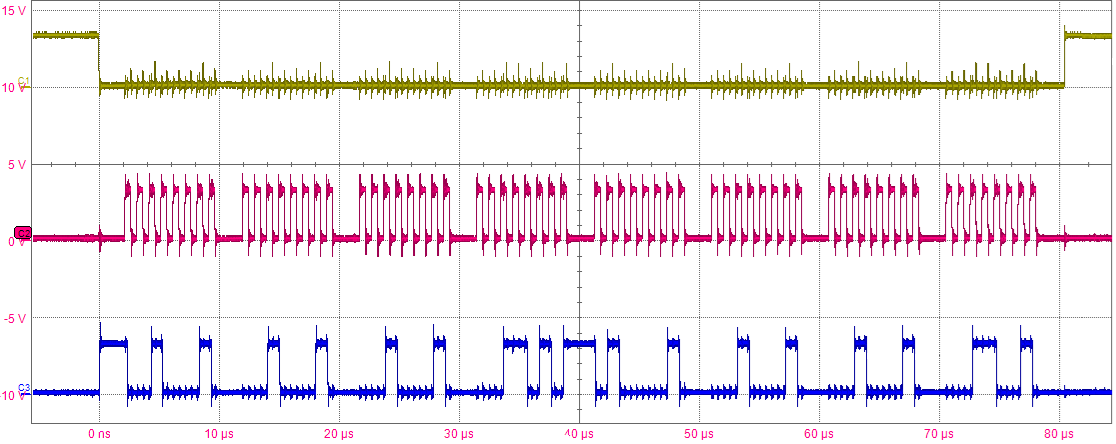
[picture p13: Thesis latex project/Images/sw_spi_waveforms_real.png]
    
    \caption{Formele de undă ce exemplifică funcționarea modulului SPI.}%
\label{fig:sw_spi_waveforms_real}
\end{figure}
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

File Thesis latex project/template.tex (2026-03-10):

\documentclass[12pt,a4paper]{report}

% --------------------- PACKAGES ---------------------
\usepackage{fontspec}             % Custom font
\usepackage{pdfpages}             % Atach PDFs
\usepackage{graphicx}             % Images
\usepackage{amsmath,amssymb}      % Math
\usepackage{caption}              % Figure/table captions
\usepackage{subcaption}           % Subfigures
\usepackage{geometry}             % Margins
\usepackage{fancyhdr}             % Headers/footers
\usepackage{tocloft}              % ToC/List formatting
\usepackage[acronym,nonumberlist]{glossaries} % Acronyms
\usepackage[hidelinks]{hyperref}  % Hyperlinks
\usepackage{titlesec}             % Section title styling
\usepackage{listings}             % Source code
\usepackage{chngcntr}             % Counter tweaks
\usepackage{tabularx}             % Tables
\usepackage{tikz}                 % Graphs
\usepackage{pgfplots}             % Plots
\pgfplotsset{compat=1.18}         % Or latest version supported by Overleaf
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
    {\thesubsection}{16pt}{}
\titlespacing{\subsection}{1.25cm}{10pt}{0pt}

\renewcommand{\normalsize}{\fontsize{12}{16}\selectfont}
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

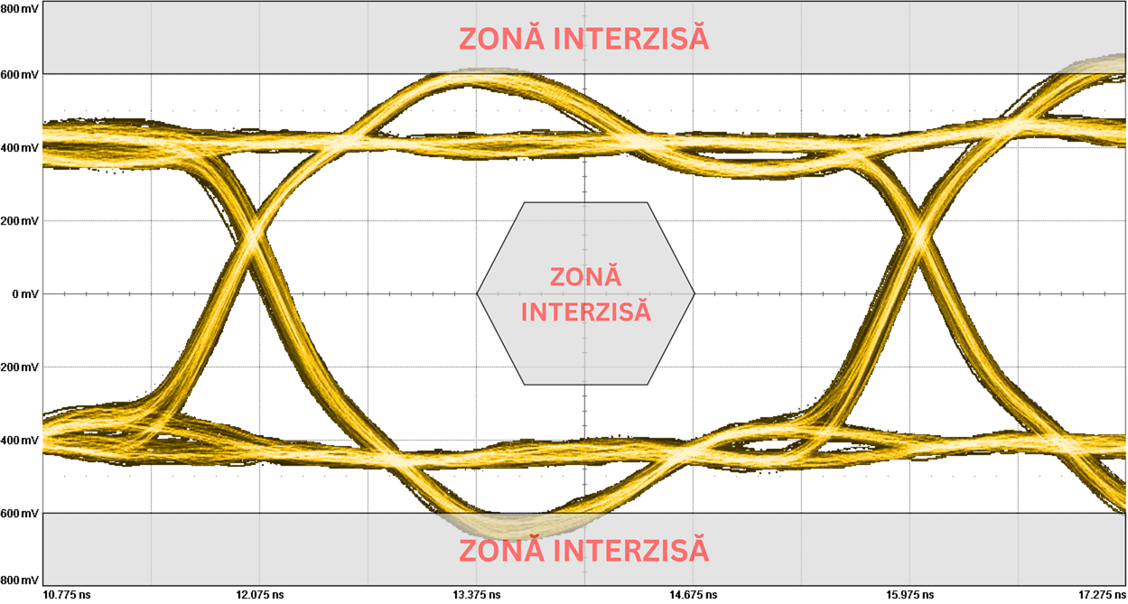
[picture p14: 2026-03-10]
Thesis latex project/Images/ts_eye_diagram.png

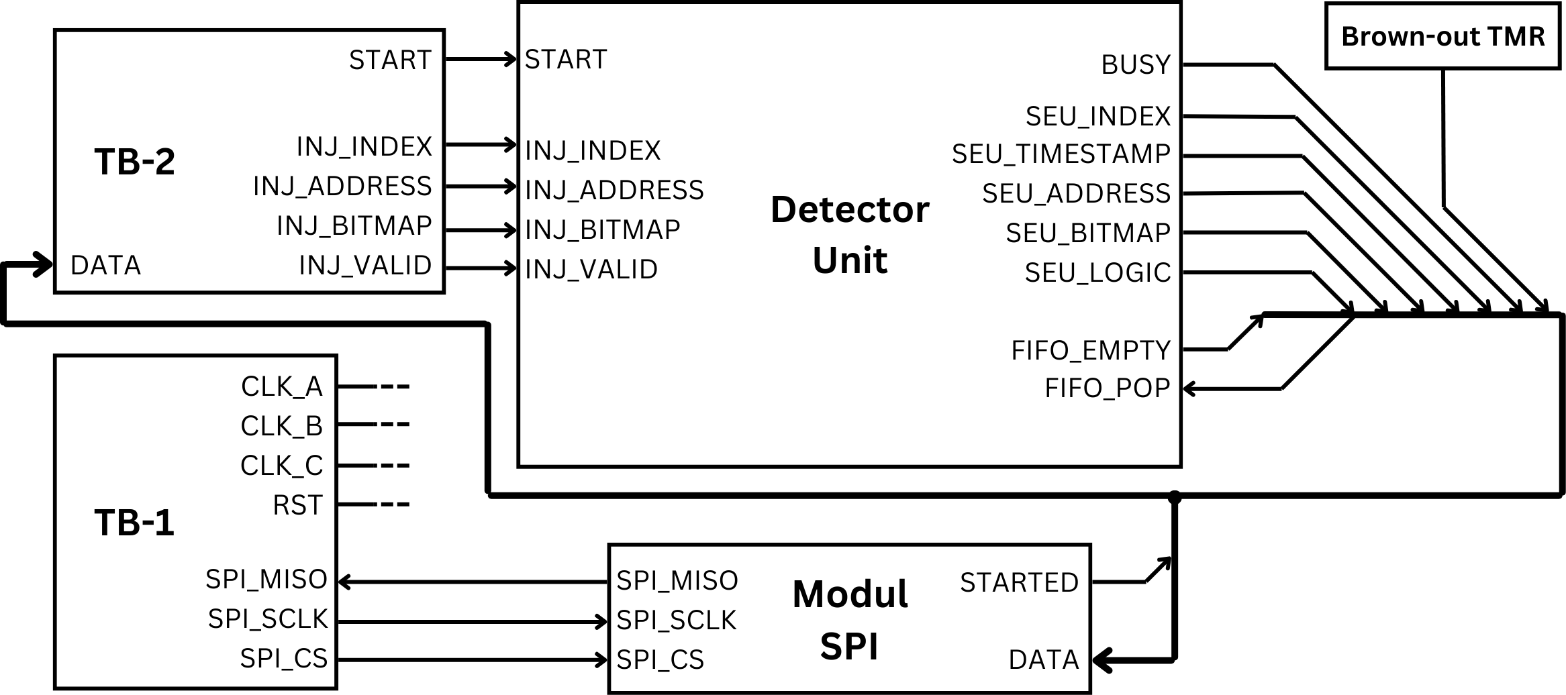
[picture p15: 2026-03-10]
Thesis latex project/Images/ts_simulation_diagram.png

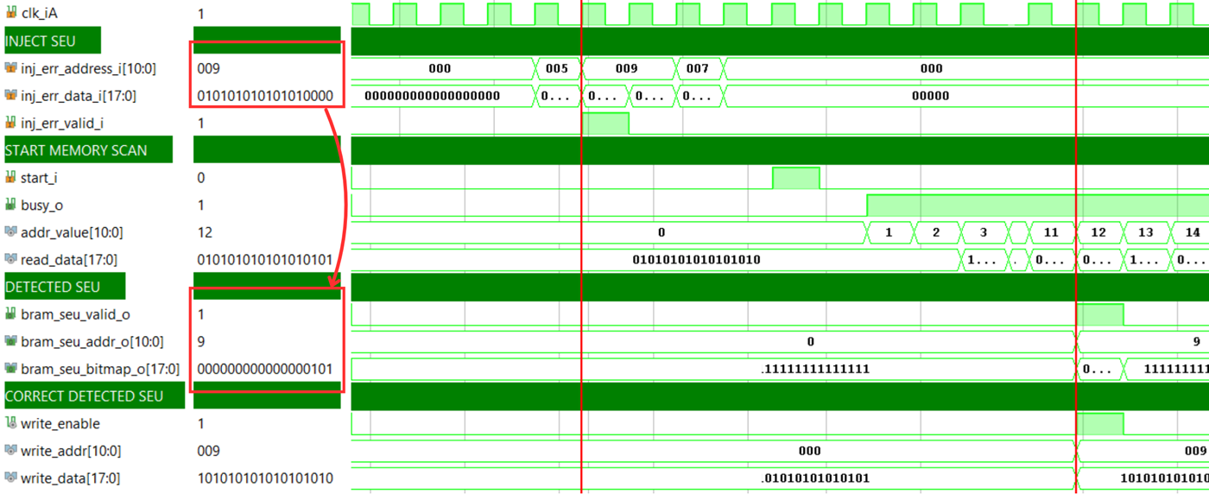
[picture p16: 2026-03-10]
Thesis latex project/Images/ts_main_sim.png

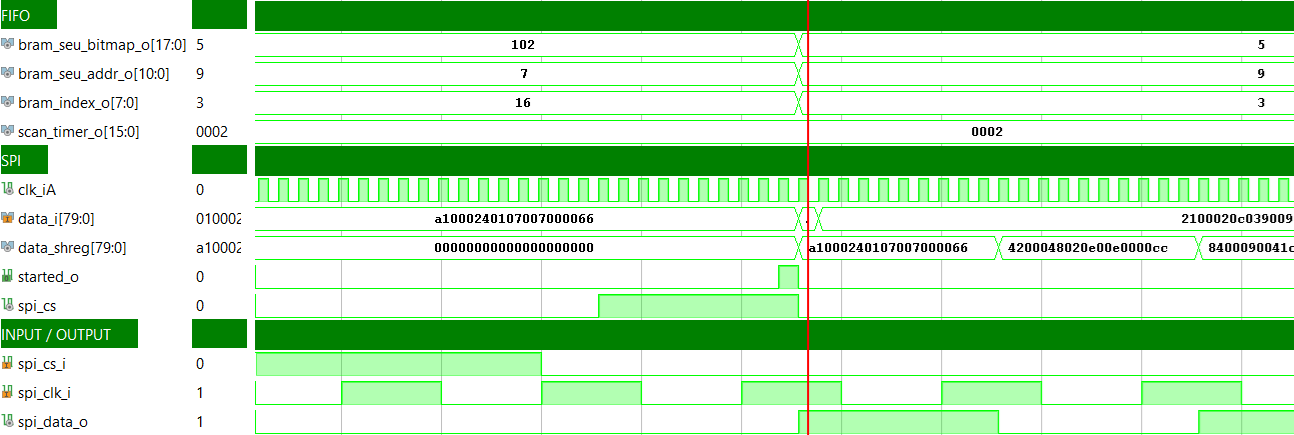
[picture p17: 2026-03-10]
Thesis latex project/Images/Main_spi.png

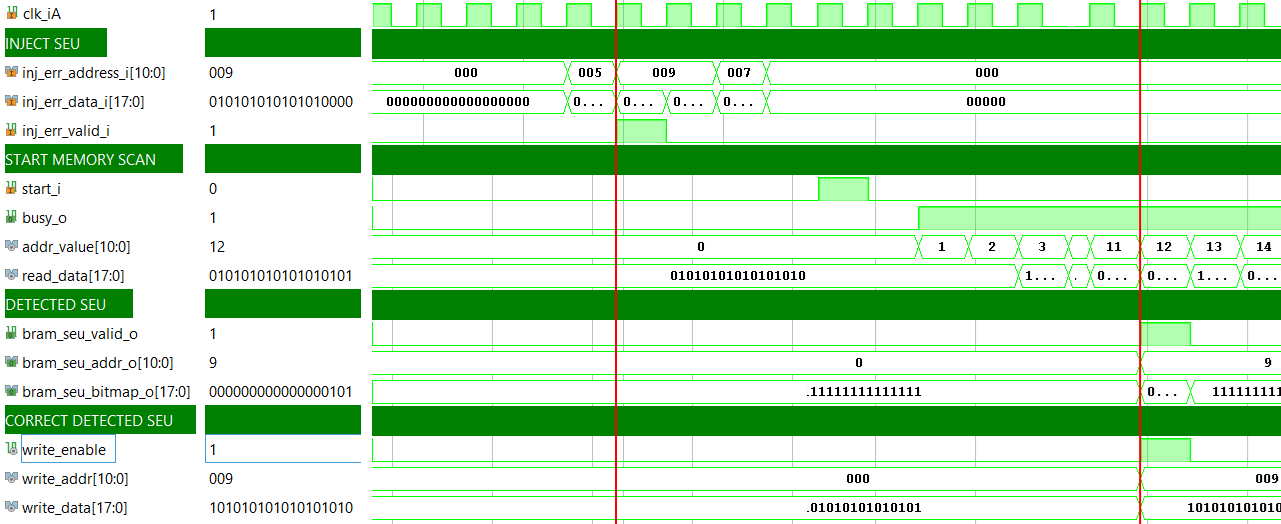
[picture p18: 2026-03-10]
Thesis latex project/Images/Main_sim2.png

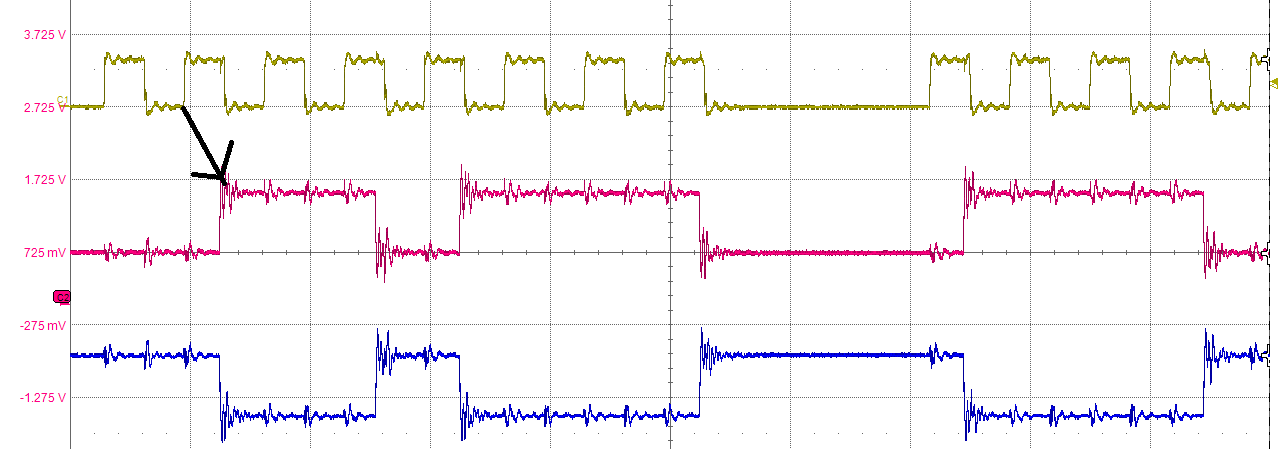
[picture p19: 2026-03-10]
Thesis latex project/Images/SPI_Frame_Diff_2.png

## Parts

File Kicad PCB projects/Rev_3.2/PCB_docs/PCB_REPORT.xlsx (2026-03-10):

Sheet: FPGA pinout
Bank | VCCO | Interface | IO standard | Signal | Pin | Description | Is clock capable?
0 | 3,3V | JTAG | LVCMOS33 | JTAG_TDI | R13 | TDI | NO
 |  |  |  | JTAG_TDO | U13 | TDO | NO
 |  |  |  | JTAG_TMS | T13 | TMS | NO
 |  |  |  | JTAG_TCK | V12 | TCK | YES
13 | 3,3V | - | - | - | - | - | -
14 | 3,3V | CAN | LVCMOS33 | CAN_H | AA20 | Positive diferential CAN pin | NO
 |  |  |  | CAN_L | AB20 | Negative diferential CAN pin | NO
 |  | QSPI (NOR flash) | LVCMOS33 | SPI_1_SCK | L12 (Bank 0) | SCK | YES
 |  |  |  | SPI_1_MOSI_IO0 | P22 | IO0 | NO
 |  |  |  | SPI_1_MISO_IO1 | R22 | IO1 | NO
 |  |  |  | SPI_1_IO2 | P21 | IO2 | NO
 |  |  |  | SPI_1_IO3 | R21 | IO3 | NO
 |  |  |  | SPI_1_CS_FLASH | T19 | CS | NO
 |  | CONN | LVCMOS33 | CONN_1 | W21 | Unused PC/104 pin | NO
 |  |  |  | CONN_2 | Y21 | Unused PC/104 pin | NO
 |  |  |  | CONN_3 | Y22 | Unused PC/104 pin | NO
 |  |  |  | CONN_4 | W22 | Unused PC/104 pin | NO
 |  | IIC - MASTER | LVCMOS33 | IIC_SDA | K2 | SDA from the FPGA to the OBC | NO
 |  |  |  | IIC_SCL | L3 | SCL from the FPGA to the OBC | NO
15 | 3,3V | CONN | LVCMOS33 | CONN_5 | N22 | Unused PC/104 pin | NO
 |  |  |  | CONN_6 | M22 | Unused PC/104 pin | NO
 |  |  |  | CONN_7 | K21 | Unused PC/104 pin | NO
 |  |  |  | CONN_8 | K22 | Unused PC/104 pin | NO
 |  |  |  | CONN_9 | J21 | Unused PC/104 pin | YES
 |  |  |  | CONN_10 | J20 | Unused PC/104 pin | YES
16 | 2,5V | SPI LVDS | LVDS25 | SPI_SCK_P | B17 | Positive LVDS SCK input | YES
 |  |  |  | SPI_SCK_N | B18 | Negative LVDS SCK input | YES
 |  |  |  | SPI_MOSI_IO0_P | B20 | Positive LVDS MOSI input | NO
 |  |  |  | SPI_MOSI_IO0_N | A20 | Negative LVDS MOSI input | NO
 |  |  |  | SPI_MISO_IO1_P | C22 | Positive LVDS MISO output | NO
 |  |  |  | SPI_MISO_IO1_N | B22 | Negative LVDS MISO output | NO
 |  |  |  | SPI_CS_P | E22 | Positive LVDS CS input | NO
 |  |  |  | SPI_CS_N | D22 | Negative LVDS CS input | NO
 |  | LVDS CLK | LVDS25 | SYS_CLK_P | E19 | Positive LVDS CLK input | YES
 |  |  |  | SYS_CLK_N | D19 | Negative LVDS CLK input | YES
34 | 3,3V | PMOD | LVCMOS33 | GPIO_1 | AA1 | 3,3V capable IO pin | NO
 |  |  |  | GPIO_2 | AB1 | 3,3V capable IO pin | NO
 |  |  |  | GPIO_3 | AB2 | 3,3V capable IO pin | NO
 |  |  |  | GPIO_4 | AB3 | 3,3V capable IO pin | NO
 |  |  |  | GPIO_5 | AB5 | 3,3V capable IO pin | NO
 |  |  |  | GPIO_6 | AB6 | 3,3V capable IO pin | NO
 |  |  |  | GPIO_7 | AB7 | 3,3V capable IO pin | NO
 |  |  |  | GPIO_8 | AB8 | 3,3V capable IO pin | NO
35 | 3,3V | IIC - SLAVE | LVCMOS33 | IIC_SDA | AB21 | SDA from the FPGA to the INAs | NO
 |  |  |  | IIC_SCL | AB22 | SCL from the FPGA to the INAs | YES

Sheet: CONNECTORS
Connector | Interface | Available | Signal | Description
PC/104 52-pin header 02 x 26 1mm hole diameter | UNUSED | YES | CONN_1 | Unused pin
 |  |  | CONN_2 | Unused pin
 |  |  | CONN_3 | Unused pin
 |  |  | CONN_4 | Unused pin
 |  |  | CONN_5 | Unused pin
 |  |  | CONN_6 | Unused pin
 |  |  | CONN_7 | Unused pin
 |  |  | CONN_8 | Unused pin
 |  |  | CONN_9 | Unused pin - clock capable
 |  |  | CONN_10 | Unused pin - clock capable
 | CAN | YES | CAN_H | Positive diferential CAN pin
 |  |  | CAN_L | Negative diferential CAN pin
 | IIC | YES | IIC_SDA_OBC | SDA from the FPGA to the OBC
 |  |  | IIC_SCL_OBC | SCL from the FPGA to the OBC
 | SPI LVDS | YES | SPI_SCK_P | Positive LVDS SCK input
 |  |  | SPI_SCK_N | Negative LVDS SCK input
 |  |  | SPI_MOSI_IO0_P | Positive LVDS MOSI input
 |  |  | SPI_MOSI_IO0_N | Negative LVDS MOSI input
 |  |  | SPI_MISO_IO1_P | Positive LVDS MISO output
 |  |  | SPI_MISO_IO1_N | Negative LVDS MISO output
 |  |  | SPI_CS_P | Positive LVDS CS input
 |  |  | SPI_CS_N | Negative LVDS CS input
 | POWER INPUT | YES | 5V_Unfused | 5v input
JTAG 6-pin header 01 x 06 1mm hole diameter | JTAG | YES | JTAG_TDI | TDI
 |  |  | JTAG_TDO | TDO
 |  |  | JTAG_TMS | TMS
 |  |  | JTAG_TCK | TCK
PMOD connector | EXTRA GPIO | YES | GPIO_1 | 3,3V capable IO pin
 |  |  | GPIO_2 | 3,3V capable IO pin
 |  |  | GPIO_3 | 3,3V capable IO pin
 |  |  | GPIO_4 | 3,3V capable IO pin
 |  |  | GPIO_5 | 3,3V capable IO pin
 |  |  | GPIO_6 | 3,3V capable IO pin
 |  |  | GPIO_7 | 3,3V capable IO pin
 |  |  | GPIO_8 | 3,3V capable IO pin
 |  |  | 3,3V | 3,3V power
 |  |  | GND | Ground
POWER connector | POWER RAILS | YES | GND | Ground
 |  |  | 5V | 5V input
 |  |  | 3,3V | 3,3V power rail
 |  |  | 2,5V | 2,5V power rail
 |  |  | 1,8V | 1,8V power rail
 |  |  | VCCINT | 1V power rail

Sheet: JUMPERS
JUMPER NAME | ROLE | SHOULD BE ACTIVE
CONN_L | Connects the PC/104 CAN low pin to the FPGA | NO
CONN_H | Connects the PC/104 CAN high pin to the FPGA | NO
CONN_1 | Connects one of the PC/104 unused pin to the FPGA | ?
CONN_2 | Connects one of the PC/104 unused pin to the FPGA | ?
CONN_3 | Connects one of the PC/104 unused pin to the FPGA | ?
CONN_4 | Connects one of the PC/104 unused pin to the FPGA | ?
CONN_5 | Connects one of the PC/104 unused pin to the FPGA | ?
CONN_6 | Connects one of the PC/104 unused pin to the FPGA | ?
CONN_7 | Connects one of the PC/104 unused pin to the FPGA | ?
CONN_8 | Connects one of the PC/104 unused pin to the FPGA | ?
CONN_9 | Connects one of the PC/104 unused pin to the FPGA | ?
CONN_10 | Connects one of the PC/104 unused pin to the FPGA | ?
M0 | Connects the M0 pin to GND | YES
M1 | Connects the M1 pin to GND | NO
M2 | Connects the M2 pin to GND | NO
SDA_CONN | Connects the sda line from the two i2c busses together | NO
SCL_CONN | Connects the scl line from the two i2c busses together | NO
A0_1 | A0 address selector for 1V INA sensor | YES
A1_1 | A1 address selector for 1V INA sensor | YES
A0_2 | A0 address selector for 1,8V INA sensor | YES
A1_2 | A1 address selector for 1,8V INA sensor | YES
A0_3 | A0 address selector for 3,3V INA sensor | YES
A1_3 | A1 address selector for 3,3V INA sensor | YES
A0_4 | A0 address selector for 2,5V INA sensor | YES
A1_4 | A1 address selector for 2,5V INA sensor | YES
1V_MAIN | Connects the output of the 1V DC/DC regulator to the power rail | YES
1V8_MAIN | Connects the output of the 1,8V DC/DC regulator to the power rail | YES
2V5_MAIN | Connects the output of the 2,5V DC/DC regulator to the power rail | YES
3V3_MAIN | Connects the output of the 3,3V DC/DC regulator to the power rail | YES
1V_SNS | Connects the SENSE line of the 1V DC/DC regulator to the power rail either after the shunt or close to the FPGA | YES
1V8_SNS | Connects the SENSE line of the 1,8V DC/DC regulator to the power rail either after the shunt or close to the FPGA | YES
2V5_SNS | Connects the SENSE line of the 2,5V DC/DC regulator to the power rail either after the shunt or close to the FPGA | YES
3V3_SNS | Connects the SENSE line of the 3,3V DC/DC regulator to the power rail either after the shunt or close to the FPGA | YES

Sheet: COMPONENTS
Component type | Reference | Quantity | Description | Value | Populate | Mouser link
Capacitors | 10TPC100M | 6 | Tantalum Capacitors - Polymer 10VDC 100uF 20% ESR 50mOhm | 100uF | NO | https://ro.mouser.com/ProductDetail/Panasonic/10TPC100MT?qs=4qgZ1GHix0WglR%2Fylq435w%3D%3D
 | 6TPE680MI | 2 | Tantalum Capacitors - Polymer 4VDC 680uF 20% ESR 35mOhm | 680uF | NO | https://ro.mouser.com/ProductDetail/Panasonic/6TPE680MI?qs=OE1iw1LrrPHKncXKJmsWJg%3D%3D
 | GRM033R60J475ME05D | 65 | MLCC - SMD/SMT 4.7 uF 6.3 VDC 20% 0201 X5R | 4.7uF | NO | https://ro.mouser.com/ProductDetail/Murata-Electronics/GRM033R60J475ME05D?qs=hd1VzrDQEGhyRq0WEnT3HQ%3D%3D
 | GRM21BR61A476ME15L | 49 | MLCC - SMD/SMT 47 uF 10 VDC 20% 0805 X5R | 47uF | NO | https://ro.mouser.com/ProductDetail/Murata-Electronics/GRM21BR61A476ME15L?qs=hNud%2FORuBR2%2FEB7WUpdltg%3D%3D
 | GRM033R60J104KE19J | 22 | MLCC - SMD/SMT 0.1 uF 6.3 VDC 10% 0201 X5R | 0.1uF | NO | https://ro.mouser.com/ProductDetail/Murata-Electronics/GRM033R60J104KE19J?qs=QDXoN8f0aYLGz627rNNvOA%3D%3D
 | GRM033R60J474ME90D | 51 | MLCC - SMD/SMT 0.47 uF 6.3 VDC 20% 0201 X5R | 0.47uF | NO | https://ro.mouser.com/ProductDetail/Murata-Electronics/GRM033R60J474ME90D?qs=P%2FC4Eoq9CDzkaSI5k1fFGQ%3D%3D
 | GRM21BC81C226ME44L | 9 | MLCC - SMD/SMT 22 uF 16 VDC 20% 0805 X6S | 22uF | NO | https://eu.mouser.com/ProductDetail/Murata-Electronics/GRM21BC81C226ME44L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
 | GRM1555C1H180JA01D | 2 | MLCC - SMD/SMT 18 pF 50 VDC 5% 0402 C0G (NP0) AEC-Q200 | 18pF | NO | https://ro.mouser.com/ProductDetail/Murata-Electronics/GRM1555C1H180JA01D?qs=mRkWMvdT7ZKEkI5QPHEfww%3D%3D
LED | LTST-C171KGKT | 8 | Green 2V LED | 2V | NO | https://ro.mouser.com/ProductDetail/Lite-On/LTST-C171KGKT?qs=j1zysehuyChA38z%2F%252BFfUSw%3D%3D
Fuse | SF-1206F400-2 | 5 | Surface Mount Fuses 4A Fast Acting 1206 SinglFuse | 4A | NO | https://ro.mouser.com/ProductDetail/Bourns/SF-1206F400-2?qs=GIQXYiEeHGDRkl%2FZefjp7A%3D%3D
Ferrite Bead | MPZ2012S101AT000 | 5 | 100ohms 4A 20mOhms 0805 Ferrite Chip | 100ohms | NO | https://ro.mouser.com/ProductDetail/TDK/MPZ2012S101AT000?qs=pLY5GE0xrmKpe1XYPmVCHA%3D%3D
MICRO-USB connector | 10104110-0001LF | 1 |  |  | NO | https://eu.mouser.com/ProductDetail/Amphenol-FCI/10104110-0001LF?qs=3wMSRtz0%252BRoQF1VV4tle7w%3D%3D
Micro SD Card Socket | DM3AT-SF-PEJM5 | 1 |  |  | NO | https://ro.mouser.com/ProductDetail/Hirose-Connector/DM3AT-SF-PEJM5?qs=LZSZKJVF%252B2WTDKp%252BR7IYAQ%3D%3D
Slide Switch | EG1271 | 1 | Slide Switches PC MNT SLIDE SPDT |  | NO | https://eu.mouser.com/ProductDetail/E-Switch/500SSP1S1M6QEA?qs=rR7wk9eDIwqJRqIHjYTyBg%3D%3D
MOSFET | FDV301N | 4 | 0.5A Id, 50V Vds, N-Channel MOSFET, SOT-23 |  | NO | https://eu.mouser.com/ProductDetail/onsemi-Fairchild/FDV301N?qs=HK%252BeIG1iaahv7gPT5tsFJQ%3D%3D
Resistors | RC0805FR-0710KL | 8 | SMD 10 kOhms 125 mW 0805 1% | 10k | NO | https://eu.mouser.com/ProductDetail/YAGEO/RC0805FR-0710KL?qs=sGAEpiMZZMtlubZbdhIBIOFKZRuegvHPJZwbdSsMnYE%3D
 | RC0805FR-07200RL | 8 | SMD 200 Ohms 125 mW 0805 1% | 200 | NO | https://ro.mouser.com/ProductDetail/YAGEO/RC0805FR-07200RL?qs=8Y8p%252BasKcI6eOmWZIjO4jQ%3D%3D
 | RT0805FRE07158KL | 1 | SMD 1/8W 158K ohm 1% 50ppm | 158k | NO | https://ro.mouser.com/ProductDetail/YAGEO/RT0805FRE07158KL?qs=4CyHz7GXqSi8U2O0pkds%2FA%3D%3D
 | AC0805FR-073K3L | 2 | SMD 3.3kOhms 1/8W 0805 1 % | 3.3k | NO | https://eu.mouser.com/ProductDetail/YAGEO/AC0805FR-073K3L
 | RC0805FR-07100RL | 5 | SMD 100 Ohms 125 mW 0805 1% | 100 | NO | https://eu.mouser.com/ProductDetail/YAGEO/RC0805FR-07100RL
 | RC0805FR-07665RL | 1 | SMD 665 Ohms 125 mW 0805 1% | 665 | NO | https://ro.mouser.com/ProductDetail/YAGEO/RC0805FR-07665RL?qs=VclHTCIjYN54CwNVmC3Nxw%3D%3D
 | RC0805FR-07324KL | 1 | SMD 324 kOhms 125 mW 0805 1% | 324k | NO | https://ro.mouser.com/ProductDetail/YAGEO/RC0805FR-07324KL?qs=sGAEpiMZZMtG0KNrPCHnjTg0x5DoQJ5PoA25YBZ7Tes%3D
 | RC0805FR-071KL | 4 | SMD 1 kOhms 125 mW 0805 1% | 1K | NO | https://eu.mouser.com/ProductDetail/YAGEO/RC0805FR-071KL?qs=sGAEpiMZZMtlubZbdhIBINUJ4p5cMnF1Rv8sEVwr4ss%3D
 | RT0805BRD071K13L | 1 | SMD 1/8W 1.13k ohm 1% 50ppm | 1.13k | NO | https://ro.mouser.com/ProductDetail/YAGEO/RT0805BRD071K13L?qs=4CyHz7GXqSh0o2BWNoNnCQ%3D%3D
 | RC0805FR-074K7L | 5 | SMD 4.7 kOhms 125 mW 0805 1% | 4.7k | NO | https://ro.mouser.com/ProductDetail/YAGEO/RC0805FR-074K7L?qs=VLOqbHBAO5cYXbrd7RTmuQ%3D%3D
 | RC0805FR-075K76L | 1 | SMD 5.76 kOhms 125 mW 0805 1% | 5.76k | NO | https://ro.mouser.com/ProductDetail/YAGEO/RC0805FR-075K76L?qs=g6xwsc4j%252B%2FrUFlFAiSU1tQ%3D%3D
 | RC0805FR-072KL | 1 | SMD 2 kOhms 125 mW 0805 1% | 2k | NO | https://ro.mouser.com/ProductDetail/YAGEO/RC0805FR-072KL?qs=QrWOOBGzeCYk%2Fx0gjMNmqg%3D%3D
 | RC0805FR-1312KL | 1 | SMD 12kOhms 1/8W 0805 1% | 12k | NO | https://eu.mouser.com/ProductDetail/YAGEO/RC0805FR-1312KL?qs=sGAEpiMZZMtlubZbdhIBIHucEnbnlIRRbluzsxBMjiU%3D
Shunt resistors | WSKW06123L000FEA | 4 | SMD 1watt 0.003ohms 1% | 0.003 | NO | https://eu.mouser.com/ProductDetail/Vishay-Dale/WSKW06123L000FEA?qs=AvgxZrxb8y2dBJZEB%2FTE7w%3D%3D
Tactile switch | TS-1002-07026 | 1 | Push button switch |  | NO | https://jlcpcb.com/partdetail/XUNPU-TS_100207026/C455095
DC-DC converter | TPS84320RUQR | 4 | Input: 4,6-12v Output: 0,6-5,5v @ 6A / 3A Programmable soft start | 3A | NO | https://eu.mouser.com/ProductDetail/Texas-Instruments/TPS84320RUQR?qs=KC2rBGieF4oGQTnzNiOl5g%3D%3D
Current Monitor | INA219BxD | 4 | With I2C Interface, SOIC-8 |  | NO | https://www.mouser.co.uk/ProductDetail/Texas-Instruments/INA219BID?qs=1WmUhT%2FVMIOEOZ2ZxHP1Nw%3D%3D
FPGA | XC7A200T-SBG484 | 1 | XC7A200T-1SBG484I |  | NO | https://ro.mouser.com/ProductDetail/AMD-Xilinx/XC7A200T-1SBG484I?qs=rrS6PyfT74cKMCfq5oXivw%3D%3D
NOR flash | S25FL512SAGMFV010 | 1 | SPI, dual/quad SPI NOR Flash | 512Mbit | NO | https://ro.mouser.com/ProductDetail/Infineon-Technologies/S25FL512SAGMFV010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
LVDS SPI driver | SN65LVDT14PWR | 1 |  |  | NO | https://eu.mouser.com/ProductDetail/Texas-Instruments/SN65LVDT14PWR?qs=QViXGNcIEAuLLT5UGRfEhQ%3D%3D
USB to UART/JTAG | FT2232HL | 1 | USB to: UART, FIFO, JTAG, I2C, SPI, etc. |  | NO | https://ro.mouser.com/ProductDetail/FTDI/FT2232HL-REEL?qs=D1%2FPMqvA100v7FHcEx164g%3D%3D
EEPROM | 93LC56BT-I/OT | 1 | Serial EEPROM, 93 Series, 5.0V, DIP-8/SOIC-8 |  | NO | https://ro.mouser.com/ProductDetail/Microchip-Technology/93LC56BT-I-OT?qs=lQv0JY93vrc7B5Rh5LPW8g%3D%3D
Crystal oscilator | ECS-120-18-4X-CKM | 1 | 12MHz crystal 18pF |  | NO | https://ro.mouser.com/ProductDetail/ECS/ECS-120-18-4X-CKM?qs=7MVldsJ5Uayqj3jfg9wxgA%3D%3D
LVDS oscilator | AX3DAF1-100.0000T | 1 | 100 MHz LVDS Oscilator 3,3v Max jitter: 0,5ps |  | NO | https://eu.mouser.com/ProductDetail/ABRACON/AX3DAF1-100.0000T?qs=Zz7%252BYVVL6bHHWH52x8gS4g%3D%3D
Header jumpers | 999-19-310-06 | 4 |  | 01x02 | NO | https://eu.mouser.com/ProductDetail/Preci-dip/999-19-310-06?qs=KBM%2FMdeLKej4fv40VCR9qg%3D%3D
Header connectors | ESQ-126-39-G-D | 1 | PC/104 02x26 connector | 02x26 | NO | https://ro.mouser.com/ProductDetail/Samtec/ESQ-126-39-G-D?qs=Cqqh%252BS766wm7W672HSOlSA%3D%3D
 | TSW-103-07-G-S | 1 | Power enable jumper | 03x01 | NO | https://ro.mouser.com/ProductDetail/Samtec/TSW-103-07-G-S?qs=iT52DjcXudtntd1jApTIAw%3D%3D
 | TSW-103-07-G-D | 1 | Mode select jumper | 03x02 | NO | https://ro.mouser.com/ProductDetail/Samtec/TSW-103-07-G-D?qs=rHlcMk0NooLQemUaDbI%2FEA%3D%3D
 | TSW-106-07-L-S | 1 | JTAG connector | 06x01 | NO | https://ro.mouser.com/ProductDetail/Samtec/TSW-106-07-L-S?qs=jyzYFa4oMQgsGVdgcTCixg%3D%3D

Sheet: TESTING
Test category | Tasks | Description | Used tool | Test successful | Tested boards | Passed boards | Notes
Mechanical | Check general integrity | look if all the connectors are propperly soldered | (2-4) Eyes | YES | A, B | A, B
 |  | no solder droplets stuck on the board |  | YES | A, B | A, B
 |  | check PCB height |  | YES | A, B | A, B | final design height should be 1.6mm ±0.1mm 1,6mm - height of PCB
 |  | check max height of components |  | YES | A, B | A, B
 |  | check no missing components |  | YES | A, B | A, B
 | Check weight | check weight of the board | Scale | NO
Thermal | Check static temperature | temperature of the LDOs | IR camera | YES | A | A | No significant heat detected
 |  | temperature of the FPGA |  | YES | A | A
 | Check temps during maximum utilization | temperature of the LDOs during maximum rated current draw |  | YES | A | A
 |  | temperature of the FPGA during intense design implementation | IR camera Internal registers | YES | A | A
Power | Chack static power draw | power draw of the whole board | USB power meter | YES | A | A | 1,02 W under no utilization (AICORS_blank project)
 |  | power draw of the fpga | INAs | YES | A | A | 1,02 W - same measurement INA and USB power meter
 |  | power draw of each voltage level | INAs | YES | A | A | Measured with Arduino UNO, using AICORS_blank project 0,996 V - 0,237 mA 1,812 V - 0,276 mA 2,524 V - 0,004 mA 3,320 V - 0,084 mA
 |  | power draw of the FPGA during intense design implementation | INAs | YES | A |  | 1,63 W - measured with USB meter 2,5 W - measured with INA possible wrong program no significant heat
 | Check clocks | measure output frequency of both oscilators | Oscilloscope | YES | A, B | A, B
 | Check JTAG fuctionality | upload an FPGA program using JTAG connector | Vivado | YES | A, B | A, B
 |  | upload a bitfile to NOR flash |  | YES | A, B | A, B | device is a Cypress/Spansion 512Mbit s25fl512s-spi-x1_x2_x4
Communication | Check line integrity | upload IO_tester design to FPGA and check continuity | Oscilloscope | YES | A, B | A, B
 |  | check if frequency of more than 400KHz is possible on I2C lines |  | YES | A | A | worked fine at 500 MHz
 | Check communication | upload Demo_tester design to FPGA and check communication through UART and I2C | Vivado | YES | A | A
 |  | make Eye diagram for I2C communication |  | NO
 |  | make Eye diagram for SPI communication? |  | NO
Notes
INA Arduino program output | Voltage: 0.996 --- Shunt voltage[mV]: 1.780 --- Current: 972 --- Power: 49 --- Current[A]: 0.237 --- Power[W]: 0.239
 | Voltage: 1.812 --- Shunt voltage[mV]: 2.090 --- Current: 1141 --- Power: 103 --- Current[A]: 0.279 --- Power[W]: 0.503
 | Voltage: 2.524 --- Shunt voltage[mV]: 0.030 --- Current: 16 --- Power: 2 --- Current[A]: 0.004 --- Power[W]: 0.010
 | Voltage: 3.320 --- Shunt voltage[mV]: 0.630 --- Current: 344 --- Power: 57 --- Current[A]: 0.084 --- Power[W]: 0.278
 | Total power [W]: 1.030

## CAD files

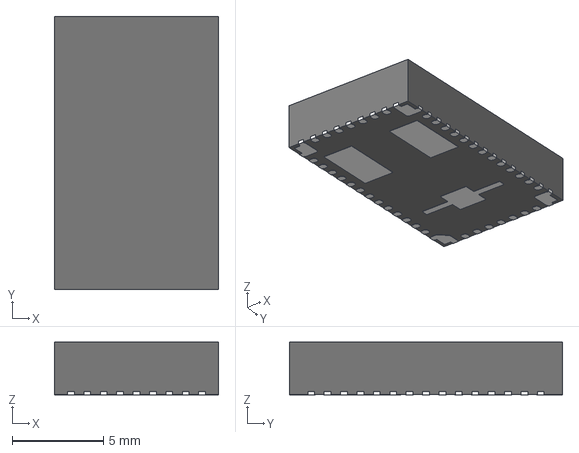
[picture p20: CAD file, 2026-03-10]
Kicad PCB projects/Rev_3.2/RUQ0047A.stp
9.00 x 15.0 x 2.90 mm
FRAME
MOLD

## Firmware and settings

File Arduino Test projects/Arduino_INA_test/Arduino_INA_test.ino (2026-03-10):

#include <Wire.h>

// Reads the 4 INA219 sensors through i2c and print the colected data

const int I2C_ADDRESS_2V5 = 0b1000011;
const int I2C_ADDRESS_3V3 = 0b1000010;
const int I2C_ADDRESS_1V8 = 0b1000001;
const int I2C_ADDRESS_1V  = 0b1000000;
const int I2C_ADDRESS_DUMMY = 0b1010101;

// The calibration register MUST be set for the INA to work. 
// FOR REV 2 - 55924 - R_Shunt = 0.003, Maximum current = 8A, so the conversion is easier
// FOR REV 3 - 22369 - R_Shunt = 0.02, Maximum current = 3A
<<<<<<< HEAD
const uint32_t calibration = 19000;
=======
const uint32_t calibration = 55924;
>>>>>>> 647cb9f9868c92c107b0d32821dc7a1e607e85ea

void setup() {
  Wire.begin();
  Wire.setClock(100000);
  Serial.begin(9600);

  // Initial configuration for every INA  
  // MUST be done at every power-on
  for(int i=0; i<4; i++){
    uint8_t i2c_address = 0b1000000 + i;

    write_two_register(i2c_address, 0x00, (1 << 15));           //reset

    write_two_register(i2c_address, 0x00, 0b0000011111111111);  //status
    write_two_register(i2c_address, 0x05, calibration);         //calibration
  }
} 

void loop() {  
  double total_power = 0;

  // Itterates through the sensors and collects the data 
  for(int i=0; i<4; i++){
    uint8_t i2c_address = 0b1000000 + i;

    Serial.println();
    Serial.print("Voltage: ");
    Serial.print(read_voltage(i2c_address), 3);

    Serial.print(" --- Shunt voltage[mV]: ");
    Serial.print(read_shunt_voltage(i2c_address), 3);

    Serial.print(" --- Current: ");
    int current = read_current(i2c_address);
    Serial.print(current);
    
    Serial.print(" --- Power: ");
    int power = read_power(i2c_address);
    Serial.print(power);

    double current_calc = (double)current / 4096;
    Serial.print(" --- Current[A]: ");
    Serial.print(current_calc, 3);

    double power_calc = (double)power * ((double)20/4096);
    Serial.print(" --- Power[W]: ");
    Serial.print(power_calc, 3);

    total_power += power_calc;
  }

  Serial.print("\nTotal power [W]: ");
  Serial.println(total_power, 3);

  delay(500);
}

double read_shunt_voltage(uint8_t i2c_address){
  write_one_register(i2c_address, 0x1);
  return (double)read_16bit_register(i2c_address) / 100;
}

double read_voltage(uint8_t i2c_address){
  write_one_register(i2c_address, 0x2);
  uint16_t value = read_16bit_register(i2c_address);

  // The first 3 bits are status bits
  // The register is 10bit
  // A lsb is 4mV
  return (double)(value >> 3) / 1000 * 4;
}

int read_power(uint8_t i2c_address){
  write_one_register(i2c_address, 0x3);
  return read_16bit_register(i2c_address);
}

int read_current(uint8_t i2c_address){
  write_one_register(i2c_address, 0x4);
  return read_16bit_register(i2c_address);
}

uint16_t read_16bit_register(uint8_t i2c_address)
{
  uint16_t value = 0;
  uint8_t c;
  
  Wire.requestFrom((int)i2c_address, (int)2);
  while (Wire.available()) { 
    c = Wire.read(); 
    value = (value << 8) + c;  
  }
  
  return value;
}

void write_two_register(uint8_t i2c_address, uint8_t reg_address, uint16_t reg_data){
  Wire.beginTransmission(i2c_address);
  Wire.write(reg_address);
  Wire.write(reg_data >> 8);
  Wire.write(reg_data);
  handleI2CError(Wire.endTransmission());
}

void write_one_register(int i2c_address, int reg_address)
{
  Wire.beginTransmission(i2c_address);
  Wire.write(reg_address);
  handleI2CError(Wire.endTransmission());
}

void handleI2CError(int errorCode) {
    switch (errorCode) {
        case 0:
            break;
        case 1:
            Serial.println("\nError: Data too long to fit in transmit buffer.\n");
            break;
        case 2:
            //Serial.println("\nError: Received NACK on transmit of address.\n");
            break;
        case 3:
            Serial.println("\nError: Received NACK on transmit of data.\n");
            break;
        case 4:
            Serial.println("\nError: Other error.\n");
            break;
        case 5:
            Serial.println("\nError: Timeout.\n");
            break;
        default:
            Serial.println("\nError: Unknown error code.\n");
            break;
    }
}

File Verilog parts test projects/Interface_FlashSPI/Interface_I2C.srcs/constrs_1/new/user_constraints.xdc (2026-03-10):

# FLASH SPI
set_property IOSTANDARD LVTTL [get_ports flash_mosi_o]
set_property PACKAGE_PIN P22 [get_ports flash_mosi_o]

set_property IOSTANDARD LVTTL [get_ports flash_miso_i]
set_property PACKAGE_PIN R22 [get_ports flash_miso_i]

set_property IOSTANDARD LVTTL [get_ports flash_cs_o]
set_property PACKAGE_PIN T19 [get_ports flash_cs_o]


# SD SPI
set_property IOSTANDARD LVTTL [get_ports spi_mosi_i]
set_property PACKAGE_PIN D1 [get_ports spi_mosi_i]

set_property IOSTANDARD LVTTL [get_ports spi_miso_o]
set_property PACKAGE_PIN B1 [get_ports spi_miso_o]

set_property IOSTANDARD LVTTL [get_ports spi_clk_i]
set_property PACKAGE_PIN H3 [get_ports spi_clk_i]

set_property IOSTANDARD LVTTL [get_ports spi_cs_i]
set_property PACKAGE_PIN E1 [get_ports spi_cs_i]


# CONFIGURATION
#set_property CONFIG_MODE SPIx4 [current_design]
#set_property BITSTREAM.CONFIG.SPI_BUSWIDTH 4 [current_design]
#set_property BITSTREAM.CONFIG.CONFIGRATE 33 [current_design]
#set_property BITSTREAM.GENERAL.COMPRESS TRUE [current_design]
#set_property BITSTREAM.GENERAL.PERFRAMECRC YES [current_design]

#set_property BITSTREAM.CONFIG.CONFIGFALLBACK ENABLE [current_design]
#set_property BITSTREAM.CONFIG.NEXT_CONFIG_ADDR 32'h00A00000 [current_design]

# To write a flash config file use:
# 32'h00100000 = 1Mb
# write_cfgmem -format mcs -force -interface SPIX4 -size 64 -loadbit "up 0 C:/Users/andre/IMPORTANT/ICDT/Interface_FlashSPI/Interface_I2C.runs/impl_1/top_golden.bit up 0x0A00000 C:/Users/andre/IMPORTANT/ICDT/Interface_FlashSPI/Interface_I2C.runs/impl_1/top.bit" C:/Users/andre/IMPORTANT/ICDT/Interface_FlashSPI/Interface_I2C.runs/impl_1/flash.mcs
